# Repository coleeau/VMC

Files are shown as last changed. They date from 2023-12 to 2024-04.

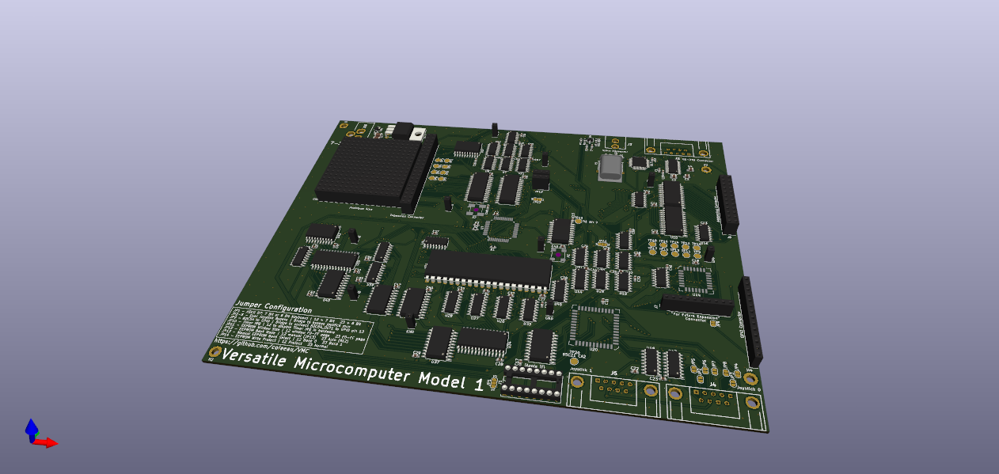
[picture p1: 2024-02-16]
Hardware/Micro/Micro.png

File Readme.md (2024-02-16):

# Versatile Micro Computer

The Versatile Micro Computer (VMC for short) is a 6502 platform designed to be Powerful, expandable, and versatile

The VMC was designed as a project to express everything I have leared in electrical engineering,
and as a way to learn more concepts in electrical engineering, computer engineering and computer science

## Repository layout

- Hardware: KiCad files for the Hardware side of the VMC
- Reference: Reference documents
- Software: all sorts of programs
- Tools: Tools for testing

## Licensing

- Hardware: Global License applies to all files
- Reference: License depends on file. Global license likely applies to any non datasheet files.
- Software: Global License applies to all files outside of /3rd Party Software/ folder
- Tools: Global License does not apply to any file.

## Roadmap

### Complete

- Design of Revision 1 Arcitecture
- Revision 1 PCB Layout
- Bootstrap Program "Rudimentery"
- Assemble and
### In Progress

- Test Revision 1 Hardware
- Write Bios

### Planned

- Port Basic
- Replace glue logic with PLD for better speed and cost efficiancy

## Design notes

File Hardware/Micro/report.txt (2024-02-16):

Info: Processing symbol 'C1:Capacitor_SMD:C_0603_1608Metric_Pad1.08x0.95mm_HandSolder'.
Info: Processing symbol 'C2:Capacitor_SMD:C_0805_2012Metric_Pad1.18x1.45mm_HandSolder'.
Info: Processing symbol 'JP8:Jumper:SolderJumper-2_P1.3mm_Open_RoundedPad1.0x1.5mm'.
Info: Processing symbol 'C3:Capacitor_SMD:C_0805_2012Metric_Pad1.18x1.45mm_HandSolder'.
Info: Processing symbol 'JP9:Jumper:SolderJumper-2_P1.3mm_Open_RoundedPad1.0x1.5mm'.
Info: Processing symbol 'C4:Capacitor_SMD:C_0805_2012Metric_Pad1.18x1.45mm_HandSolder'.
Info: Processing symbol 'JP10:Jumper:SolderJumper-3_P1.3mm_Open_RoundedPad1.0x1.5mm_NumberLabels'.
Info: Processing symbol 'C5:Capacitor_SMD:C_0603_1608Metric_Pad1.08x0.95mm_HandSolder'.
Info: Processing symbol 'C6:Capacitor_SMD:C_0603_1608Metric_Pad1.08x0.95mm_HandSolder'.
Info: Processing symbol 'C7:Capacitor_SMD:C_0603_1608Metric_Pad1.08x0.95mm_HandSolder'.
Info: Processing symbol 'C8:Capacitor_SMD:C_0603_1608Metric_Pad1.08x0.95mm_HandSolder'.
Info: Processing symbol 'U19:Package_SO:SOIC-14_3.9x8.7mm_P1.27mm'.
Info: Processing symbol 'C9:Capacitor_SMD:C_0603_1608Metric_Pad1.08x0.95mm_HandSolder'.
Info: Processing symbol 'JP11:Jumper:SolderJumper-3_P1.3mm_Bridged12_RoundedPad1.0x1.5mm_NumberLabels'.
Info: Processing symbol 'C10:Capacitor_SMD:C_0603_1608Metric_Pad1.08x0.95mm_HandSolder'.
Info: Processing symbol 'U9:Package_SO:SOIC-14_3.9x8.7mm_P1.27mm'.
Info: Processing symbol 'C11:Capacitor_SMD:C_0603_1608Metric_Pad1.08x0.95mm_HandSolder'.
Info: Processing symbol 'JP12:Jumper:SolderJumper-3_P1.3mm_Bridged12_RoundedPad1.0x1.5mm_NumberLabels'.
Info: Processing symbol 'C12:Capacitor_SMD:C_0603_1608Metric_Pad1.08x0.95mm_HandSolder'.
Info: Processing symbol 'U23:Package_SO:SOIC-20W_7.5x12.8mm_P1.27mm'.
Info: Processing symbol 'C13:Capacitor_SMD:C_0603_1608Metric_Pad1.08x0.95mm_HandSolder'.
Info: Processing symbol 'JP13:Connector_PinSocket_2.54mm:PinSocket_1x03_P2.54mm_Vertical'.
Info: Processing symbol 'C14:Capacitor_SMD:C_0603_1608Metric_Pad1.08x0.95mm_HandSolder'.
Info: Processing symbol 'U10:Package_SO:SOIC-24W_7.5x15.4mm_P1.27mm'.
Info: Processing symbol 'C15:Capacitor_SMD:C_0603_1608Metric_Pad1.08x0.95mm_HandSolder'.
Info: Processing symbol 'Q4:Package_TO_SOT_SMD:SOT-23_Handsoldering'.
Info: Processing symbol 'C16:Capacitor_SMD:C_0603_1608Metric_Pad1.08x0.95mm_HandSolder'.
Info: Processing symbol 'R1:Resistor_SMD:R_0603_1608Metric_Pad0.98x0.95mm_HandSolder'.
Info: Processing symbol 'C17:Capacitor_SMD:C_0603_1608Metric_Pad1.08x0.95mm_HandSolder'.
Info: Processing symbol 'R2:Resistor_SMD:R_0603_1608Metric_Pad0.98x0.95mm_HandSolder'.
Info: Processing symbol 'C18:Capacitor_SMD:C_0603_1608Metric_Pad1.08x0.95mm_HandSolder'.
Info: Processing symbol 'R3:Resistor_SMD:R_0603_1608Metric_Pad0.98x0.95mm_HandSolder'.
Info: Processing symbol 'C19:Capacitor_SMD:C_0603_1608Metric_Pad1.08x0.95mm_HandSolder'.
Info: Processing symbol 'R4:Resistor_SMD:R_0603_1608Metric_Pad0.98x0.95mm_HandSolder'.
Info: Processing symbol 'C20:Capacitor_SMD:C_0603_1608Metric_Pad1.08x0.95mm_HandSolder'.
Info: Processing symbol 'R5:Resistor_SMD:R_0603_1608Metric_Pad0.98x0.95mm_HandSolder'.
Info: Processing symbol 'C21:Capacitor_SMD:C_0603_1608Metric_Pad1.08x0.95mm_HandSolder'.
Info: Processing symbol 'R6:Resistor_SMD:R_0603_1608Metric_Pad0.98x0.95mm_HandSolder'.
Info: Processing symbol 'C22:Capacitor_SMD:C_0603_1608Metric_Pad1.08x0.95mm_HandSolder'.
Info: Processing symbol 'R7:Resistor_SMD:R_0603_1608Metric_Pad0.98x0.95mm_HandSolder'.
Info: Processing symbol 'C23:Capacitor_SMD:C_0603_1608Metric_Pad1.08x0.95mm_HandSolder'.
Info: Processing symbol 'U24:Package_DIP:DIP-40_W15.24mm'.
Info: Processing symbol 'C24:Capacitor_SMD:C_0603_1608Metric_Pad1.08x0.95mm_HandSolder'.
Info: Processing symbol 'U20:Package_LCC:PLCC-44'.
Info: Processing symbol 'C25:Capacitor_SMD:C_0603_1608Metric_Pad1.08x0.95mm_HandSolder'.
Info: Processing symbol 'R8:Resistor_SMD:R_0603_1608Metric_Pad0.98x0.95mm_HandSolder'.
Info: Processing symbol 'C26:Capacitor_SMD:C_0603_1608Metric_Pad1.08x0.95mm_HandSolder'.
Info: Processing symbol 'U21:Package_SO:SOIC-14_3.9x8.7mm_P1.27mm'.
Info: Processing symbol 'C27:Capacitor_SMD:C_0603_1608Metric_Pad1.08x0.95mm_HandSolder'.
Info: Processing symbol 'U12:Package_SO:SOIC-20W_7.5x12.8mm_P1.27mm'.
Info: Processing symbol 'C28:Capacitor_SMD:C_0603_1608Metric_Pad1.08x0.95mm_HandSolder'.
Info: Processing symbol 'R9:Resistor_SMD:R_0603_1608Metric_Pad0.98x0.95mm_HandSolder'.
Info: Processing symbol 'C29:Capacitor_SMD:C_0603_1608Metric_Pad1.08x0.95mm_HandSolder'.
Info: Processing symbol 'R10:Resistor_SMD:R_0603_1608Metric_Pad0.98x0.95mm_HandSolder'.
Info: Processing symbol 'C30:Capacitor_SMD:C_0603_1608Metric_Pad1.08x0.95mm_HandSolder'.
Info: Processing symbol 'R11:Resistor_SMD:R_0603_1608Metric_Pad0.98x0.95mm_HandSolder'.
Info: Processing symbol 'C31:Capacitor_SMD:C_0603_1608Metric_Pad1.08x0.95mm_HandSolder'.
Info: Processing symbol 'TP1:TestPoint:TestPoint_Pad_D2.5mm'.
Info: Processing symbol 'C32:Capacitor_SMD:C_0603_1608Metric_Pad1.08x0.95mm_HandSolder'.
Info: Processing symbol 'U13:Package_TO_SOT_THT:TO-220-3_Horizontal_TabDown'.
Info: Processing symbol 'C33:Capacitor_SMD:C_0603_1608Metric_Pad1.08x0.95mm_HandSolder'.
Info: Processing symbol 'TP2:TestPoint:TestPoint_Pad_D2.5mm'.
Info: Processing symbol 'C34:Capacitor_SMD:C_0603_1608Metric_Pad1.08x0.95mm_HandSolder'.
Info: Processing symbol 'U22:Package_SO:SOIC-14_3.9x8.7mm_P1.27mm'.
Info: Processing symbol 'C35:Capacitor_SMD:C_0603_1608Metric_Pad1.08x0.95mm_HandSolder'.
Info: Processing symbol 'TP3:TestPoint:TestPoint_Pad_D2.5mm'.
Info: Processing symbol 'C36:Capacitor_SMD:C_0603_1608Metric_Pad1.08x0.95mm_HandSolder'.
Info: Processing symbol 'U14:Package_LCC:PLCC-28'.
Info: Processing symbol 'C37:Capacitor_SMD:C_0603_1608Metric_Pad1.08x0.95mm_HandSolder'.
Info: Processing symbol 'TP4:TestPoint:TestPoint_Pad_D2.5mm'.
Info: Processing symbol 'C38:Capacitor_SMD:C_0603_1608Metric_Pad1.08x0.95mm_HandSolder'.
Info: Processing symbol 'U15:Package_SO:SOIC-20W_7.5x12.8mm_P1.27mm'.
Info: Processing symbol 'C39:Capacitor_SMD:C_0603_1608Metric_Pad1.08x0.95mm_HandSolder'.
Info: Processing symbol 'TP5:TestPoint:TestPoint_Pad_D2.5mm'.
Info: Processing symbol 'C40:Capacitor_SMD:C_0603_1608Metric_Pad1.08x0.95mm_HandSolder'.
Info: Processing symbol 'U16:Package_SO:SOIC-14_3.9x8.7mm_P1.27mm'.
Info: Processing symbol 'C41:Capacitor_SMD:C_0603_1608Metric_Pad1.08x0.95mm_HandSolder'.
Info: Processing symbol 'TP6:TestPoint:TestPoint_Pad_D2.5mm'.
Info: Processing symbol 'C42:Capacitor_SMD:C_0603_1608Metric_Pad1.08x0.95mm_HandSolder'.
Info: Processing symbol 'U17:Package_QFP:TQFP-48_7x7mm_P0.5mm'.
Info: Processing symbol 'C43:Capacitor_SMD:C_0603_1608Metric_Pad1.08x0.95mm_HandSolder'.
Info: Processing symbol 'TP7:TestPoint:TestPoint_Pad_D2.5mm'.
Info: Processing symbol 'C44:Capacitor_SMD:C_0603_1608Metric_Pad1.08x0.95mm_HandSolder'.
Info: Processing symbol 'U11:Package_SO:SOIC-24W_7.5x15.4mm_P1.27mm'.
Info: Processing symbol 'C45:Capacitor_SMD:C_0603_1608Metric_Pad1.08x0.95mm_HandSolder'.
Info: Processing symbol 'TP8:TestPoint:TestPoint_Pad_D2.5mm'.
Info: Processing symbol 'C46:Capacitor_SMD:C_0603_1608Metric_Pad1.08x0.95mm_HandSolder'.
Info: Processing symbol 'U32:Package_SO:SOIC-14_3.9x8.7mm_P1.27mm'.
Info: Processing symbol 'C47:Capacitor_SMD:C_0603_1608Metric_Pad1.08x0.95mm_HandSolder'.
Info: Processing symbol 'U1:Package_QFP:MQFP-44_10x10mm_P0.8mm'.
Info: Processing symbol 'C48:Capacitor_SMD:C_0603_1608Metric_Pad1.08x0.95mm_HandSolder'.
Info: Processing symbol 'U2:Package_SO:SOIC-28W_7.5x17.9mm_P1.27mm'.
Info: Processing symbol 'C49:'.
Info: Processing symbol 'U40:Package_SO:SOIC-16_3.9x9.9mm_P1.27mm'.
Info: Processing symbol 'C50:'.
Info: Processing symbol 'U39:Package_SO:SOIC-16_3.9x9.9mm_P1.27mm'.
Info: Processing symbol 'C51:Capacitor_SMD:C_0603_1608Metric_Pad1.08x0.95mm_HandSolder'.
Info: Processing symbol 'U3:Package_SO:SOIC-28W_7.5x17.9mm_P1.27mm'.
Info: Processing symbol 'C52:Capacitor_SMD:C_0603_1608Metric_Pad1.08x0.95mm_HandSolder'.
Info: Processing symbol 'U4:Package_SO:SOIC-14_3.9x8.7mm_P1.27mm'.
Info: Processing symbol 'C53:Capacitor_SMD:C_0603_1608Metric_Pad1.08x0.95mm_HandSolder'.
Info: Processing symbol 'U31:Package_SO:SOIC-14_3.9x8.7mm_P1.27mm'.
Info: Processing symbol 'C54:Capacitor_SMD:C_0603_1608Metric_Pad1.08x0.95mm_HandSolder'.
Info: Processing symbol 'U5:Package_SO:SOIC-14_3.9x8.7mm_P1.27mm'.
Info: Processing symbol 'C55:Capacitor_SMD:C_0603_1608Metric_Pad1.08x0.95mm_HandSolder'.
Info: Processing symbol 'U30:Package_SO:SOIC-14_3.9x8.7mm_P1.27mm'.
Info: Processing symbol 'C56:Capacitor_SMD:C_0603_1608Metric_Pad1.08x0.95mm_HandSolder'.
Info: Processing symbol 'U29:Package_SO:SOIC-14_3.9x8.7mm_P1.27mm'.
Info: Processing symbol 'C57:Capacitor_SMD:C_0603_1608Metric_Pad1.08x0.95mm_HandSolder'.
Info: Processing symbol 'U28:Package_SO:SOIC-16_3.9x9.9mm_P1.27mm'.
Info: Processing symbol 'D1:Diode_SMD:D_SOD-123'.
Info: Processing symbol 'D2:Diode_SMD:D_SOD-123'.
Info: Processing symbol 'D3:Diode_SMD:D_SOD-123'.
Info: Processing symbol 'D4:Diode_SMD:D_PowerDI-123'.
Info: Processing symbol 'U27:Package_SO:SOIC-16_3.9x9.9mm_P1.27mm'.
Info: Processing symbol 'F1:Fuse:Fuse_0603_1608Metric_Pad1.05x0.95mm_HandSolder'.
Info: Processing symbol 'U6:Package_SO:SOIC-14_3.9x8.7mm_P1.27mm'.
Info: Processing symbol 'J1:Package_DIP:DIP-16_W7.62mm_Socket'.
Info: Processing symbol 'J2:SamacSys_Parts:L717SDE09PA4CH3F'.
Info: Processing symbol 'U38:Package_SO:SOIC-16_3.9x9.9mm_P1.27mm'.
Info: Processing symbol 'U37:Package_SO:SOIC-20W_7.5x12.8mm_P1.27mm'.
Info: Processing symbol 'J3:1560099E'.
Info: Processing symbol 'U26:Package_SO:SOIC-16_3.9x9.9mm_P1.27mm'.
Info: Processing symbol 'J4:SamacSys_Parts:L717SDE09PA4CH3F'.
Info: Processing symbol 'U36:Package_SO:SOIC-20W_7.5x12.8mm_P1.27mm'.
Info: Processing symbol 'U35:Package_SO:SOIC-20W_7.5x12.8mm_P1.27mm'.
Info: Processing symbol 'J5:SamacSys_Parts:L717SDE09PA4CH3F'.
Info: Processing symbol 'U34:Package_SO:SOIC-28W_7.5x17.9mm_P1.27mm'.
Info: Processing symbol 'U33:Package_SO:SOIC-16_3.9x9.9mm_P1.27mm'.
Info: Processing symbol 'J6:Connector_PinSocket_2.54mm:PinSocket_1x14_P2.54mm_Vertical'.
Info: Processing symbol 'J7:Connector_PinSocket_2.54mm:PinSocket_1x10_P2.54mm_Vertical'.
Info: Processing symbol 'J8:Connector_PinSocket_2.54mm:PinSocket_2x11_P2.54mm_Vertical'.
Info: Processing symbol 'U7:Package_SO:SOIC-14_3.9x8.7mm_P1.27mm'.
Info: Processing symbol 'J9:Connector_PinSocket_2.54mm:PinSocket_2x20_P2.54mm_Vertical'.
Info: Processing symbol 'U25:Package_SO:SOIC-28W_7.5x18.7mm_P1.27mm'.
Info: Processing symbol 'J10:694106301002_1'.
Info: Processing symbol 'U8:Package_SO:SOIC-14_3.9x8.7mm_P1.27mm'.
Info: Processing symbol 'JP1:Jumper:SolderJumper-3_P1.3mm_Open_RoundedPad1.0x1.5mm_NumberLabels'.
Info: Processing symbol 'U18:Package_SO:TSSOP-28_4.4x9.7mm_P0.65mm'.
Info: Processing symbol 'JP2:Jumper:SolderJumper-2_P1.3mm_Open_RoundedPad1.0x1.5mm'.
Info: Processing symbol 'JP3:Jumper:SolderJumper-2_P1.3mm_Open_RoundedPad1.0x1.5mm'.
Info: Processing symbol 'JP4:Jumper:SolderJumper-2_P1.3mm_Open_RoundedPad1.0x1.5mm'.
Info: Processing symbol 'JP5:Jumper:SolderJumper-2_P1.3mm_Open_RoundedPad1.0x1.5mm'.
Info: Processing symbol 'JP6:Jumper:SolderJumper-2_P1.3mm_Open_RoundedPad1.0x1.5mm'.
Info: Processing symbol 'JP7:Jumper:SolderJumper-2_P1.3mm_Open_RoundedPad1.0x1.5mm'.
Info: Processing symbol 'U41:Package_SO:SOIC-16_3.9x9.9mm_P1.27mm'.
Info: Processing symbol 'U42:Package_SO:SOIC-20W_7.5x12.8mm_P1.27mm'.
Info: Processing symbol 'U43:Package_SO:SOIC-20W_7.5x12.8mm_P1.27mm'.
Info: Processing symbol 'U44:Package_SO:SOIC-16_3.9x9.9mm_P1.27mm'.
Info: Processing symbol 'U45:Package_SO:SOIC-16_3.9x9.9mm_P1.27mm'.
Info: Processing symbol 'U46:Package_SO:SOIC-14_3.9x8.7mm_P1.27mm'.
Info: Processing symbol 'U47:Package_SO:SOIC-16_3.9x9.9mm_P1.27mm'.
Info: Processing symbol 'U48:Package_SO:SOIC-16_3.9x9.9mm_P1.27mm'.
Info: Processing symbol 'U49:Package_SO:SOIC-14_3.9x8.7mm_P1.27mm'.
Info: Processing symbol 'X1:Oscillator:Oscillator_SMD_Fordahl_DFAS11-4Pin_7.0x5.0mm'.
Info: Processing symbol 'X2:Oscillator:Oscillator_SMD_Abracon_ASV-4Pin_7.0x5.1mm_HandSoldering'.
Info: Processing symbol 'Y1:Crystal:Crystal_HC49-U_Horizontal_1EP_style2'.
Add C17 (footprint 'Capacitor_SMD:C_0603_1608Metric_Pad1.08x0.95mm_HandSolder').
Add C18 (footprint 'Capacitor_SMD:C_0603_1608Metric_Pad1.08x0.95mm_HandSolder').
Add C19 (footprint 'Capacitor_SMD:C_0603_1608Metric_Pad1.08x0.95mm_HandSolder').
Add C20 (footprint 'Capacitor_SMD:C_0603_1608Metric_Pad1.08x0.95mm_HandSolder').
Add C21 (footprint 'Capacitor_SMD:C_0603_1608Metric_Pad1.08x0.95mm_HandSolder').
Add C22 (footprint 'Capacitor_SMD:C_0603_1608Metric_Pad1.08x0.95mm_HandSolder').
Add C23 (footprint 'Capacitor_SMD:C_0603_1608Metric_Pad1.08x0.95mm_HandSolder').
Add C24 (footprint 'Capacitor_SMD:C_0603_1608Metric_Pad1.08x0.95mm_HandSolder').
Add C25 (footprint 'Capacitor_SMD:C_0603_1608Metric_Pad1.08x0.95mm_HandSolder').
Add C26 (footprint 'Capacitor_SMD:C_0603_1608Metric_Pad1.08x0.95mm_HandSolder').
Add C27 (footprint 'Capacitor_SMD:C_0603_1608Metric_Pad1.08x0.95mm_HandSolder').
Add C28 (footprint 'Capacitor_SMD:C_0603_1608Metric_Pad1.08x0.95mm_HandSolder').
Add C29 (footprint 'Capacitor_SMD:C_0603_1608Metric_Pad1.08x0.95mm_HandSolder').
Add C30 (footprint 'Capacitor_SMD:C_0603_1608Metric_Pad1.08x0.95mm_HandSolder').
Add C31 (footprint 'Capacitor_SMD:C_0603_1608Metric_Pad1.08x0.95mm_HandSolder').
Add C32 (footprint 'Capacitor_SMD:C_0603_1608Metric_Pad1.08x0.95mm_HandSolder').
Add C33 (footprint 'Capacitor_SMD:C_0603_1608Metric_Pad1.08x0.95mm_HandSolder').
Add C34 (footprint 'Capacitor_SMD:C_0603_1608Metric_Pad1.08x0.95mm_HandSolder').
Add C35 (footprint 'Capacitor_SMD:C_0603_1608Metric_Pad1.08x0.95mm_HandSolder').
Add C36 (footprint 'Capacitor_SMD:C_0603_1608Metric_Pad1.08x0.95mm_HandSolder').
Add C37 (footprint 'Capacitor_SMD:C_0603_1608Metric_Pad1.08x0.95mm_HandSolder').
Add C38 (footprint 'Capacitor_SMD:C_0603_1608Metric_Pad1.08x0.95mm_HandSolder').
Add C39 (footprint 'Capacitor_SMD:C_0603_1608Metric_Pad1.08x0.95mm_HandSolder').
Add C40 (footprint 'Capacitor_SMD:C_0603_1608Metric_Pad1.08x0.95mm_HandSolder').
Add C41 (footprint 'Capacitor_SMD:C_0603_1608Metric_Pad1.08x0.95mm_HandSolder').
Add C42 (footprint 'Capacitor_SMD:C_0603_1608Metric_Pad1.08x0.95mm_HandSolder').
Add C43 (footprint 'Capacitor_SMD:C_0603_1608Metric_Pad1.08x0.95mm_HandSolder').
Add C44 (footprint 'Capacitor_SMD:C_0603_1608Metric_Pad1.08x0.95mm_HandSolder').
Add C45 (footprint 'Capacitor_SMD:C_0603_1608Metric_Pad1.08x0.95mm_HandSolder').
Add C46 (footprint 'Capacitor_SMD:C_0603_1608Metric_Pad1.08x0.95mm_HandSolder').
Add C47 (footprint 'Capacitor_SMD:C_0603_1608Metric_Pad1.08x0.95mm_HandSolder').
Add C48 (footprint 'Capacitor_SMD:C_0603_1608Metric_Pad1.08x0.95mm_HandSolder').
Add C51 (footprint 'Capacitor_SMD:C_0603_1608Metric_Pad1.08x0.95mm_HandSolder').
Add C52 (footprint 'Capacitor_SMD:C_0603_1608Metric_Pad1.08x0.95mm_HandSolder').
Add C53 (footprint 'Capacitor_SMD:C_0603_1608Metric_Pad1.08x0.95mm_HandSolder').
Add C54 (footprint 'Capacitor_SMD:C_0603_1608Metric_Pad1.08x0.95mm_HandSolder').
Add C55 (footprint 'Capacitor_SMD:C_0603_1608Metric_Pad1.08x0.95mm_HandSolder').
Add C56 (footprint 'Capacitor_SMD:C_0603_1608Metric_Pad1.08x0.95mm_HandSolder').
Add C57 (footprint 'Capacitor_SMD:C_0603_1608Metric_Pad1.08x0.95mm_HandSolder').
Add D4 (footprint 'Diode_SMD:D_PowerDI-123').
Add F1 (footprint 'Fuse:Fuse_0603_1608Metric_Pad1.05x0.95mm_HandSolder').
Change J3 footprint from 'SamacSys_Parts:1560099E' to '1560099E'.
Add J8 (footprint 'Connector_PinSocket_2.54mm:PinSocket_2x11_P2.54mm_Vertical').
Add J9 (footprint 'Connector_PinSocket_2.54mm:PinSocket_2x20_P2.54mm_Vertical').
Add J10 (footprint '694106301002_1').
Add JP1 (footprint 'Jumper:SolderJumper-3_P1.3mm_Open_RoundedPad1.0x1.5mm_NumberLabels').
Change JP10 footprint from 'Jumper:SolderJumper-3_P1.3mm_Open_Pad1.0x1.5mm_NumberLabels' to 'Jumper:SolderJumper-3_P1.3mm_Open_RoundedPad1.0x1.5mm_NumberLabels'.
Add JP11 (footprint 'Jumper:SolderJumper-3_P1.3mm_Bridged12_RoundedPad1.0x1.5mm_NumberLabels').
Add JP12 (footprint 'Jumper:SolderJumper-3_P1.3mm_Bridged12_RoundedPad1.0x1.5mm_NumberLabels').
Add JP13 (footprint 'Connector_PinSocket_2.54mm:PinSocket_1x03_P2.54mm_Vertical').
Add net /Video/Video Combination Logic/Composite vid/Y.
Reconnect R7 pin 2 from /VIdeo/Video Combination Logic/Composite vid/Y to /Video/Video Combination Logic/Composite vid/Y.
Add net /Video/Video Combination Logic/Composite vid/CSYNC.
Reconnect R8 pin 1 from /VIdeo/Video Combination Logic/Composite vid/CSYNC to /Video/Video Combination Logic/Composite vid/CSYNC.
Add TP1 (footprint 'TestPoint:TestPoint_Pad_D2.5mm').
Add TP2 (footprint 'TestPoint:TestPoint_Pad_D2.5mm').
Add TP3 (footprint 'TestPoint:TestPoint_Pad_D2.5mm').
Add TP4 (footprint 'TestPoint:TestPoint_Pad_D2.5mm').
Add TP5 (footprint 'TestPoint:TestPoint_Pad_D2.5mm').
Add TP6 (footprint 'TestPoint:TestPoint_Pad_D2.5mm').
Add TP7 (footprint 'TestPoint:TestPoint_Pad_D2.5mm').
Add TP8 (footprint 'TestPoint:TestPoint_Pad_D2.5mm').
Update U4 symbol association from /7bcaf41d-6d3d-4f33-82ee-7daa1c8431e0/5354c1c1-bc4f-4336-8cec-d4451e44db87 to /7bcaf41d-6d3d-4f33-82ee-7daa1c8431e0/391ce00c-f2b4-4eee-bc8b-14090f666e66.
Add net Net-(U30-Pad8).
Reconnect U5 pin 5 from Net-(U5-Pad1) to Net-(U30-Pad8).
Add net Net-(U30-Pad10).
Reconnect U5 pin 1 from Net-(U5-Pad1) to Net-(U30-Pad10).
Update U6 symbol association from /7bcaf41d-6d3d-4f33-82ee-7daa1c8431e0/6c6bb8ff-625e-40b3-9856-8a58038bb5e4 to /7bcaf41d-6d3d-4f33-82ee-7daa1c8431e0/4c8455cb-f38c-4708-88b6-d5893fa9d499.
Update U7 symbol association from /7bcaf41d-6d3d-4f33-82ee-7daa1c8431e0/332360da-0865-4aff-a77d-b443ebf3b65f to /7bcaf41d-6d3d-4f33-82ee-7daa1c8431e0/6dddda0c-0e40-49b6-8176-9f8dc502a90e.
Update U8 symbol association from /7bcaf41d-6d3d-4f33-82ee-7daa1c8431e0/c1ef6448-b6f6-4eba-99e9-491106cb0455 to /7bcaf41d-6d3d-4f33-82ee-7daa1c8431e0/e763f917-e82a-4c54-9560-08f6f9770648.
Reconnect U8 pin 8 from Net-(U5-Pad1) to Net-(U30-Pad10).
Update U9 symbol association from /7bcaf41d-6d3d-4f33-82ee-7daa1c8431e0/9c1bae30-8146-4c0e-84f0-774d193a82bb to /7bcaf41d-6d3d-4f33-82ee-7daa1c8431e0/e4b5f2e2-700d-4896-b4c6-00f3e92178fd.
Add net Net-(J8-Pin_20).
Reconnect U10 pin 6 from unconnected-(U10-S5-Pad6) to Net-(J8-Pin_20).
Add net Net-(J8-Pin_19).
Reconnect U10 pin 5 from unconnected-(U10-S4-Pad5) to Net-(J8-Pin_19).
Add net Net-(J8-Pin_18).
Reconnect U10 pin 4 from unconnected-(U10-S3-Pad4) to Net-(J8-Pin_18).
Add net Net-(J8-Pin_17).
Reconnect U10 pin 3 from Net-(J8-Pin_10) to Net-(J8-Pin_17).
Add net unconnected-(U10-S1-Pad2).
Reconnect U10 pin 2 from Net-(J8-Pin_9) to unconnected-(U10-S1-Pad2).
Add net Net-(J8-Pin_16).
Reconnect U11 pin 17 from Net-(U11-S15) to Net-(J8-Pin_16).
Add net Net-(J8-Pin_15).
Reconnect U11 pin 16 from unconnected-(U11-S14-Pad16) to Net-(J8-Pin_15).
Add net Net-(J8-Pin_14).
Reconnect U11 pin 15 from unconnected-(U11-S13-Pad15) to Net-(J8-Pin_14).
Add net Net-(J8-Pin_13).
Reconnect U11 pin 14 from unconnected-(U11-S12-Pad14) to Net-(J8-Pin_13).
Add net Net-(J8-Pin_12).
Reconnect U11 pin 13 from unconnected-(U11-S11-Pad13) to Net-(J8-Pin_12).
Add net Net-(J8-Pin_11).
Reconnect U11 pin 11 from unconnected-(U11-S10-Pad11) to Net-(J8-Pin_11).
Reconnect U11 pin 10 from unconnected-(U11-S9-Pad10) to Net-(J8-Pin_10).
Reconnect U11 pin 9 from unconnected-(U11-S8-Pad9) to Net-(J8-Pin_9).
Add U13 (footprint 'Package_TO_SOT_THT:TO-220-3_Horizontal_TabDown').
Update U19 symbol association from /60bf3c7c-7133-4ca1-aa44-3c0fc6d461d6/3cba59ac-4426-4a73-b4f4-1560fd894bbd/b821332d-7200-400b-bb4b-fe5db0de1882 to /60bf3c7c-7133-4ca1-aa44-3c0fc6d461d6/3cba59ac-4426-4a73-b4f4-1560fd894bbd/c3ecb09d-51e2-4e99-a5f0-d144f7a4d6c6.
Add net /Video/Video Combination Logic/VSYNC.
Reconnect U19 pin 5 from /VIdeo/Video Combination Logic/VSYNC to /Video/Video Combination Logic/VSYNC.
Add net /Video/Video Combination Logic/HSYNC.
Reconnect U19 pin 4 from /VIdeo/Video Combination Logic/HSYNC to /Video/Video Combination Logic/HSYNC.
Add net /Video/Video Combination Logic/DOT_OUT.
Reconnect U19 pin 2 from /VIdeo/Video Combination Logic/DOT_OUT to /Video/Video Combination Logic/DOT_OUT.
Update U21 symbol association from /7bcaf41d-6d3d-4f33-82ee-7daa1c8431e0/e98823ee-305d-44fd-81ae-f2e59adfc01e to /7bcaf41d-6d3d-4f33-82ee-7daa1c8431e0/8e518423-3594-4b1e-a90a-5ccb484f70fb.
Reconnect U21 pin 14 from unconnected-(U21E-VCC-Pad14) to +5V.
Reconnect U21 pin 7 from unconnected-(U21E-GND-Pad7) to GND.
Update U22 symbol association from /df04dcad-608f-4a5f-9459-edcdeb427672/7047d1ab-0072-46ed-9065-c20aee2d31ad to /df04dcad-608f-4a5f-9459-edcdeb427672/e3c288b7-e6fb-4a5a-a702-b2b577d59b8c.
Reconnect U22 pin 5 from Net-(U11-S15) to Net-(J8-Pin_16).
Update U24 properties.
Reconnect U24 pin 40 from /VIdeo/Video Combination Logic/VSYNC to /Video/Video Combination Logic/VSYNC.
Reconnect U24 pin 39 from /VIdeo/Video Combination Logic/HSYNC to /Video/Video Combination Logic/HSYNC.
Add net /Video/CHRAM_Adress_Mux/RS0.
Reconnect U24 pin 38 from /VIdeo/CHRAM_Adress_Mux/RS0 to /Video/CHRAM_Adress_Mux/RS0.
Add net /Video/CHRAM_Adress_Mux/RS1.
Reconnect U24 pin 37 from /VIdeo/CHRAM_Adress_Mux/RS1 to /Video/CHRAM_Adress_Mux/RS1.
Add net /Video/CHRAM_Adress_Mux/RS2.
Reconnect U24 pin 36 from /VIdeo/CHRAM_Adress_Mux/RS2 to /Video/CHRAM_Adress_Mux/RS2.
Add net /Video/CHRAM_Adress_Mux/RS3.
Reconnect U24 pin 35 from /VIdeo/CHRAM_Adress_Mux/RS3 to /Video/CHRAM_Adress_Mux/RS3.
Add net /Video/VID_CLK_GEN/CHR_CLK.
Reconnect U24 pin 21 from /VIdeo/VID_CLK_GEN/CHR_CLK to /Video/VID_CLK_GEN/CHR_CLK.
Add net /Video/Video Combination Logic/CURSOR.
Reconnect U24 pin 19 from /VIdeo/Video Combination Logic/CURSOR to /Video/Video Combination Logic/CURSOR.
Add net /Video/Video Combination Logic/DISP_EN.
Reconnect U24 pin 18 from /VIdeo/Video Combination Logic/DISP_EN to /Video/Video Combination Logic/DISP_EN.
Add net /Video/VRAM_Adress_Mux/MA13.
Reconnect U24 pin 17 from /VIdeo/MA13 to /Video/VRAM_Adress_Mux/MA13.
Add net /Video/VRAM_Adress_Mux/MA12.
Reconnect U24 pin 16 from /VIdeo/MA12 to /Video/VRAM_Adress_Mux/MA12.
Add net /Video/MA11.
Reconnect U24 pin 15 from /VIdeo/MA11 to /Video/MA11.
Add net /Video/VRAM_Adress_Mux/MA10.
Reconnect U24 pin 14 from /VIdeo/MA10 to /Video/VRAM_Adress_Mux/MA10.
Add net /Video/VRAM_Adress_Mux/MA9.
Reconnect U24 pin 13 from /VIdeo/MA9 to /Video/VRAM_Adress_Mux/MA9.
Add net /Video/VRAM_Adress_Mux/MA8.
Reconnect U24 pin 12 from /VIdeo/MA8 to /Video/VRAM_Adress_Mux/MA8.
Add net /Video/VRAM_Adress_Mux/MA7.
Reconnect U24 pin 11 from /VIdeo/MA7 to /Video/VRAM_Adress_Mux/MA7.
Add net /Video/VRAM_Adress_Mux/MA6.
Reconnect U24 pin 10 from /VIdeo/MA6 to /Video/VRAM_Adress_Mux/MA6.
Add net /Video/VRAM_Adress_Mux/MA5.
Reconnect U24 pin 9 from /VIdeo/MA5 to /Video/VRAM_Adress_Mux/MA5.
Add net /Video/VRAM_Adress_Mux/MA4.
Reconnect U24 pin 8 from /VIdeo/MA4 to /Video/VRAM_Adress_Mux/MA4.
Add net /Video/VRAM_Adress_Mux/MA3.
Reconnect U24 pin 7 from /VIdeo/MA3 to /Video/VRAM_Adress_Mux/MA3.
Add net /Video/VRAM_Adress_Mux/MA2.
Reconnect U24 pin 6 from /VIdeo/VRAM_Adress_Mux/MA2 to /Video/VRAM_Adress_Mux/MA2.
Add net /Video/VRAM_Adress_Mux/MA1.
Reconnect U24 pin 5 from /VIdeo/MA1 to /Video/VRAM_Adress_Mux/MA1.
Add net /Video/VRAM_Adress_Mux/MA0.
Reconnect U24 pin 4 from /VIdeo/MA0 to /Video/VRAM_Adress_Mux/MA0.
Update U25 properties.
Add net /Video/CHRAM_Adress_Mux/CHRAMA8.
Reconnect U25 pin 25 from /VIdeo/CHRAM_Adress_Mux/CHRAMA8 to /Video/CHRAM_Adress_Mux/CHRAMA8.
Add net /Video/CHRAM_Adress_Mux/CHRAMA9.
Reconnect U25 pin 24 from /VIdeo/CHRAM_Adress_Mux/CHRAMA9 to /Video/CHRAM_Adress_Mux/CHRAMA9.
Add net /Video/CHRAM_Adress_Mux/CHRAMA11.
Reconnect U25 pin 23 from /VIdeo/CHRAM_Adress_Mux/CHRAMA11 to /Video/CHRAM_Adress_Mux/CHRAMA11.
Add net /Video/CHRAM_Adress_Mux/CHRAMA10.
Reconnect U25 pin 21 from /VIdeo/CHRAM_Adress_Mux/CHRAMA10 to /Video/CHRAM_Adress_Mux/CHRAMA10.
Add net /Video/CHRAM data buffer/CHRAM_D7.
Reconnect U25 pin 19 from /VIdeo/CHRAM data buffer/CHRAM_D7 to /Video/CHRAM data buffer/CHRAM_D7.
Add net /Video/CHRAM data buffer/CHRAM_D6.
Reconnect U25 pin 18 from /VIdeo/CHRAM data buffer/CHRAM_D6 to /Video/CHRAM data buffer/CHRAM_D6.
Add net /Video/CHRAM data buffer/CHRAM_D5.
Reconnect U25 pin 17 from /VIdeo/CHRAM data buffer/CHRAM_D5 to /Video/CHRAM data buffer/CHRAM_D5.
Add net /Video/CHRAM data buffer/CHRAM_D4.
Reconnect U25 pin 16 from /VIdeo/CHRAM data buffer/CHRAM_D4 to /Video/CHRAM data buffer/CHRAM_D4.
Add net /Video/CHRAM data buffer/CHRAM_D3.
Reconnect U25 pin 15 from /VIdeo/CHRAM data buffer/CHRAM_D3 to /Video/CHRAM data buffer/CHRAM_D3.
Add net /Video/CHRAM data buffer/CHRAM_D2.
Reconnect U25 pin 13 from /VIdeo/CHRAM data buffer/CHRAM_D2 to /Video/CHRAM data buffer/CHRAM_D2.
Add net /Video/CHRAM data buffer/CHRAM_D1.
Reconnect U25 pin 12 from /VIdeo/CHRAM data buffer/CHRAM_D1 to /Video/CHRAM data buffer/CHRAM_D1.
Add net /Video/CHRAM data buffer/CHRAM_D0.
Reconnect U25 pin 11 from /VIdeo/CHRAM data buffer/CHRAM_D0 to /Video/CHRAM data buffer/CHRAM_D0.
Add net /Video/CHRAM_Adress_Mux/CHRAMA0.
Reconnect U25 pin 10 from /VIdeo/CHRAM_Adress_Mux/CHRAMA0 to /Video/CHRAM_Adress_Mux/CHRAMA0.
Add net /Video/CHRAM_Adress_Mux/CHRAMA1.
Reconnect U25 pin 9 from /VIdeo/CHRAM_Adress_Mux/CHRAMA1 to /Video/CHRAM_Adress_Mux/CHRAMA1.
Add net /Video/CHRAM_Adress_Mux/CHRAMA2.
Reconnect U25 pin 8 from /VIdeo/CHRAM_Adress_Mux/CHRAMA2 to /Video/CHRAM_Adress_Mux/CHRAMA2.
Add net /Video/CHRAM_Adress_Mux/CHRAMA3.
Reconnect U25 pin 7 from /VIdeo/CHRAM_Adress_Mux/CHRAMA3 to /Video/CHRAM_Adress_Mux/CHRAMA3.
Add net /Video/CHRAM_Adress_Mux/CHRAMA4.
Reconnect U25 pin 6 from /VIdeo/CHRAM_Adress_Mux/CHRAMA4 to /Video/CHRAM_Adress_Mux/CHRAMA4.
Add net /Video/CHRAM_Adress_Mux/CHRAMA5.
Reconnect U25 pin 5 from /VIdeo/CHRAM_Adress_Mux/CHRAMA5 to /Video/CHRAM_Adress_Mux/CHRAMA5.
Add net /Video/CHRAM_Adress_Mux/CHRAMA6.
Reconnect U25 pin 4 from /VIdeo/CHRAM_Adress_Mux/CHRAMA6 to /Video/CHRAM_Adress_Mux/CHRAMA6.
Add net /Video/CHRAM_Adress_Mux/CHRAMA7.
Reconnect U25 pin 3 from /VIdeo/CHRAM_Adress_Mux/CHRAMA7 to /Video/CHRAM_Adress_Mux/CHRAMA7.
Add net unconnected-(U26-I1d-Pad13).
Reconnect U26 pin 13 from /VIdeo/VRAM_Adress_Mux/CHARD7 to unconnected-(U26-I1d-Pad13).
Add net /Video/VRAM_Adress_Mux/VRAMA11.
Reconnect U26 pin 12 from /VIdeo/VRAM_Adress_Mux/CHRAMA11 to /Video/VRAM_Adress_Mux/VRAMA11.
Reconnect U26 pin 10 from /VIdeo/VRAM_Adress_Mux/CHARD6 to /Video/VRAM_Adress_Mux/MA10.
Add net /Video/VRAM_Adress_Mux/VRAMA10.
Reconnect U26 pin 9 from /VIdeo/VRAM_Adress_Mux/CHRAMA10 to /Video/VRAM_Adress_Mux/VRAMA10.
Add net /Video/VRAM_Adress_Mux/VRAMA9.
Reconnect U26 pin 7 from /VIdeo/VRAM_Adress_Mux/CHRAMA9 to /Video/VRAM_Adress_Mux/VRAMA9.
Reconnect U26 pin 6 from /VIdeo/VRAM_Adress_Mux/CHARD5 to /Video/VRAM_Adress_Mux/MA9.
Add net /Video/VRAM_Adress_Mux/VRAMA8.
Reconnect U26 pin 4 from /VIdeo/VRAM_Adress_Mux/CHRAMA8 to /Video/VRAM_Adress_Mux/VRAMA8.
Reconnect U26 pin 3 from /VIdeo/VRAM_Adress_Mux/CHARD4 to /Video/VRAM_Adress_Mux/MA8.
Add net /Video/Select Logic/~{VRAM_CS}.
Reconnect U26 pin 1 from /VIdeo/VRAM_Adress_Mux/~{CPU}/LATCH to /Video/Select Logic/~{VRAM_CS}.
Reconnect U27 pin 13 from /VIdeo/VRAM_Adress_Mux/CHARD3 to /Video/VRAM_Adress_Mux/MA7.
Add net /Video/VRAM_Adress_Mux/VRAMA7.
Reconnect U27 pin 12 from /VIdeo/VRAM_Adress_Mux/CHRAMA7 to /Video/VRAM_Adress_Mux/VRAMA7.
Reconnect U27 pin 10 from /VIdeo/VRAM_Adress_Mux/CHARD2 to /Video/VRAM_Adress_Mux/MA6.
Add net /Video/VRAM_Adress_Mux/VRAMA6.
Reconnect U27 pin 9 from /VIdeo/VRAM_Adress_Mux/CHRAMA6 to /Video/VRAM_Adress_Mux/VRAMA6.
Add net /Video/VRAM_Adress_Mux/VRAMA5.
Reconnect U27 pin 7 from /VIdeo/VRAM_Adress_Mux/CHRAMA5 to /Video/VRAM_Adress_Mux/VRAMA5.
Reconnect U27 pin 6 from /VIdeo/VRAM_Adress_Mux/CHARD1 to /Video/VRAM_Adress_Mux/MA5.
Add net /Video/VRAM_Adress_Mux/VRAMA4.
Reconnect U27 pin 4 from /VIdeo/VRAM_Adress_Mux/CHRAMA4 to /Video/VRAM_Adress_Mux/VRAMA4.
Reconnect U27 pin 3 from /VIdeo/VRAM_Adress_Mux/CHARD0 to /Video/VRAM_Adress_Mux/MA4.
Reconnect U27 pin 1 from /VIdeo/VRAM_Adress_Mux/~{CPU}/LATCH to /Video/Select Logic/~{VRAM_CS}.
Reconnect U28 pin 13 from /VIdeo/VRAM_Adress_Mux/RS3 to /Video/VRAM_Adress_Mux/MA3.
Add net /Video/VRAM_Adress_Mux/VRAMA3.
Reconnect U28 pin 12 from /VIdeo/VRAM_Adress_Mux/CHRAMA3 to /Video/VRAM_Adress_Mux/VRAMA3.
Reconnect U28 pin 10 from /VIdeo/VRAM_Adress_Mux/RS2 to /Video/VRAM_Adress_Mux/MA2.
Add net /Video/VRAM_Adress_Mux/VRAMA2.
Reconnect U28 pin 9 from /VIdeo/VRAM_Adress_Mux/CHRAMA2 to /Video/VRAM_Adress_Mux/VRAMA2.
Add net /Video/VRAM_Adress_Mux/VRAMA1.
Reconnect U28 pin 7 from /VIdeo/VRAM_Adress_Mux/CHRAMA1 to /Video/VRAM_Adress_Mux/VRAMA1.
Reconnect U28 pin 6 from /VIdeo/VRAM_Adress_Mux/RS1 to /Video/VRAM_Adress_Mux/MA1.
Add net /Video/VRAM_Adress_Mux/VRAMA0.
Reconnect U28 pin 4 from /VIdeo/VRAM_Adress_Mux/CHRAMA0 to /Video/VRAM_Adress_Mux/VRAMA0.
Reconnect U28 pin 3 from /VIdeo/VRAM_Adress_Mux/RS0 to /Video/VRAM_Adress_Mux/MA0.
Reconnect U28 pin 1 from /VIdeo/VRAM_Adress_Mux/~{CPU}/LATCH to /Video/Select Logic/~{VRAM_CS}.
Reconnect U29 pin 6 from /VIdeo/VID_CLK_GEN/CHR_CLK to /Video/VID_CLK_GEN/CHR_CLK.
Add U30 (footprint 'Package_SO:SOIC-14_3.9x8.7mm_P1.27mm').
Update U31 properties.
Add net /Video/CHRAM_Adress_Mux/~{CPU}/LATCH.
Reconnect U31 pin 13 from /VIdeo/CHRAM_Adress_Mux/~{CPU}/LATCH to /Video/CHRAM_Adress_Mux/~{CPU}/LATCH.
Add net /Video/CHRAM data buffer/~{CHRAM_RD}.
Reconnect U31 pin 11 from /VIdeo/CHRAM data buffer/~{CHRAM_RD} to /Video/CHRAM data buffer/~{CHRAM_RD}.
Reconnect U31 pin 9 from /VIdeo/CHRAM_Adress_Mux/~{CPU}/LATCH to /Video/CHRAM_Adress_Mux/~{CPU}/LATCH.
Add net /Video/CHRAM data buffer/~{CHRAM_WE}.
Reconnect U31 pin 8 from /VIdeo/CHRAM data buffer/~{CHRAM_WE} to /Video/CHRAM data buffer/~{CHRAM_WE}.
Add net /Video/Select Logic/~{VRAM_RD}.
Reconnect U31 pin 6 from /VIdeo/Select Logic/~{VRAM_RD} to /Video/Select Logic/~{VRAM_RD}.
Reconnect U31 pin 4 from /VIdeo/Select Logic/~{VRAM_CS} to /Video/Select Logic/~{VRAM_CS}.
Add net /Video/Select Logic/~{VRAM_WE}.
Reconnect U31 pin 3 from /VIdeo/Select Logic/~{VRAM_WE} to /Video/Select Logic/~{VRAM_WE}.
Reconnect U31 pin 2 from /VIdeo/Select Logic/~{VRAM_CS} to /Video/Select Logic/~{VRAM_CS}.
Reconnect U32 pin 8 from /VIdeo/Video Combination Logic/Composite vid/CSYNC to /Video/Video Combination Logic/Composite vid/CSYNC.
Add net /Video/VID_CLK_GEN/DOT_CLK.
Reconnect U32 pin 5 from /VIdeo/VID_CLK_GEN/DOT_CLK to /Video/VID_CLK_GEN/DOT_CLK.
Add net /Video/VID_CLK_GEN/~{CHR_CLK}.
Reconnect U32 pin 4 from /VIdeo/VID_CLK_GEN/~{CHR_CLK} to /Video/VID_CLK_GEN/~{CHR_CLK}.
Reconnect U32 pin 3 from /VIdeo/VID_CLK_GEN/CHR_CLK to /Video/VID_CLK_GEN/CHR_CLK.
Add U33 (footprint 'Package_SO:SOIC-16_3.9x9.9mm_P1.27mm').
Update U34 properties.
Reconnect U34 pin 27 from /VIdeo/Select Logic/~{VRAM_WE} to /Video/Select Logic/~{VRAM_WE}.
Add net /Video/VRAM_Adress_Mux/VRAMA13.
Reconnect U34 pin 26 from /VIdeo/VRAMA13 to /Video/VRAM_Adress_Mux/VRAMA13.
Reconnect U34 pin 25 from /VIdeo/VRAMA8 to /Video/VRAM_Adress_Mux/VRAMA8.
Reconnect U34 pin 24 from /VIdeo/VRAMA9 to /Video/VRAM_Adress_Mux/VRAMA9.
Reconnect U34 pin 23 from /VIdeo/VRAMA11 to /Video/VRAM_Adress_Mux/VRAMA11.
Reconnect U34 pin 21 from /VIdeo/VRAMA10 to /Video/VRAM_Adress_Mux/VRAMA10.
Add net /Video/VRAM data buffer/VRAM_D7.
Reconnect U34 pin 19 from /VIdeo/VRAM_D7 to /Video/VRAM data buffer/VRAM_D7.
Add net /Video/VRAM data buffer/VRAM_D6.
Reconnect U34 pin 18 from /VIdeo/VRAM_D6 to /Video/VRAM data buffer/VRAM_D6.
Add net /Video/VRAM data buffer/VRAM_D5.
Reconnect U34 pin 17 from /VIdeo/VRAM_D5 to /Video/VRAM data buffer/VRAM_D5.
Add net /Video/VRAM data buffer/VRAM_D4.
Reconnect U34 pin 16 from /VIdeo/VRAM_D4 to /Video/VRAM data buffer/VRAM_D4.
Add net /Video/VRAM data buffer/VRAM_D3.
Reconnect U34 pin 15 from /VIdeo/VRAM_D3 to /Video/VRAM data buffer/VRAM_D3.
Add net /Video/VRAM data buffer/VRAM_D2.
Reconnect U34 pin 13 from /VIdeo/VRAM_D2 to /Video/VRAM data buffer/VRAM_D2.
Add net /Video/VRAM data buffer/VRAM_D1.
Reconnect U34 pin 12 from /VIdeo/VRAM_D1 to /Video/VRAM data buffer/VRAM_D1.
Add net /Video/VRAM data buffer/VRAM_D0.
Reconnect U34 pin 11 from /VIdeo/VRAM_D0 to /Video/VRAM data buffer/VRAM_D0.
Reconnect U34 pin 10 from /VIdeo/VRAMA0 to /Video/VRAM_Adress_Mux/VRAMA0.
Reconnect U34 pin 9 from /VIdeo/VRAMA1 to /Video/VRAM_Adress_Mux/VRAMA1.
Reconnect U34 pin 8 from /VIdeo/VRAMA2 to /Video/VRAM_Adress_Mux/VRAMA2.
Reconnect U34 pin 7 from /VIdeo/VRAMA3 to /Video/VRAM_Adress_Mux/VRAMA3.
Reconnect U34 pin 6 from /VIdeo/VRAMA4 to /Video/VRAM_Adress_Mux/VRAMA4.
Reconnect U34 pin 5 from /VIdeo/VRAMA5 to /Video/VRAM_Adress_Mux/VRAMA5.
Reconnect U34 pin 4 from /VIdeo/VRAMA6 to /Video/VRAM_Adress_Mux/VRAMA6.
Reconnect U34 pin 3 from /VIdeo/VRAMA7 to /Video/VRAM_Adress_Mux/VRAMA7.
Add net /Video/VRAM_Adress_Mux/VRAMA12.
Reconnect U34 pin 2 from /VIdeo/VRAMA12 to /Video/VRAM_Adress_Mux/VRAMA12.
Reconnect U35 pin 19 from /VIdeo/VRAM data buffer/~{CHRAM_RD} to /Video/Select Logic/~{VRAM_RD}.
Reconnect U35 pin 18 from /VIdeo/VRAM data buffer/CHRAM_D0 to /Video/VRAM data buffer/VRAM_D0.
Reconnect U35 pin 17 from /VIdeo/VRAM data buffer/CHRAM_D0 to /Video/VRAM data buffer/VRAM_D0.
Reconnect U35 pin 16 from /VIdeo/VRAM data buffer/CHRAM_D1 to /Video/VRAM data buffer/VRAM_D1.
Reconnect U35 pin 15 from /VIdeo/VRAM data buffer/CHRAM_D1 to /Video/VRAM data buffer/VRAM_D1.
Reconnect U35 pin 14 from /VIdeo/VRAM data buffer/CHRAM_D2 to /Video/VRAM data buffer/VRAM_D2.
Reconnect U35 pin 13 from /VIdeo/VRAM data buffer/CHRAM_D2 to /Video/VRAM data buffer/VRAM_D2.
Reconnect U35 pin 12 from /VIdeo/VRAM data buffer/CHRAM_D3 to /Video/VRAM data buffer/VRAM_D3.
Reconnect U35 pin 11 from /VIdeo/VRAM data buffer/CHRAM_D3 to /Video/VRAM data buffer/VRAM_D3.
Reconnect U35 pin 3 from D0 to D3.
Reconnect U35 pin 2 from D0 to D3.
Reconnect U35 pin 1 from /VIdeo/VRAM data buffer/~{CHRAM_WE} to /Video/Select Logic/~{VRAM_WE}.
Reconnect U36 pin 19 from /VIdeo/VRAM data buffer/~{CHRAM_RD} to /Video/Select Logic/~{VRAM_RD}.
Reconnect U36 pin 18 from /VIdeo/VRAM data buffer/CHRAM_D4 to /Video/VRAM data buffer/VRAM_D4.
Reconnect U36 pin 17 from /VIdeo/VRAM data buffer/CHRAM_D4 to /Video/VRAM data buffer/VRAM_D4.
Reconnect U36 pin 16 from /VIdeo/VRAM data buffer/CHRAM_D5 to /Video/VRAM data buffer/VRAM_D5.
Reconnect U36 pin 15 from /VIdeo/VRAM data buffer/CHRAM_D5 to /Video/VRAM data buffer/VRAM_D5.
Reconnect U36 pin 14 from /VIdeo/VRAM data buffer/CHRAM_D6 to /Video/VRAM data buffer/VRAM_D6.
Reconnect U36 pin 13 from /VIdeo/VRAM data buffer/CHRAM_D6 to /Video/VRAM data buffer/VRAM_D6.
Reconnect U36 pin 12 from /VIdeo/VRAM data buffer/CHRAM_D7 to /Video/VRAM data buffer/VRAM_D7.
Reconnect U36 pin 11 from /VIdeo/VRAM data buffer/CHRAM_D7 to /Video/VRAM data buffer/VRAM_D7.
Reconnect U36 pin 1 from /VIdeo/VRAM data buffer/~{CHRAM_WE} to /Video/Select Logic/~{VRAM_WE}.
Update U37 properties.
Add net /Video/CHRAM_Adress_Mux/CHARD0.
Reconnect U37 pin 19 from /VIdeo/CHRAM_Adress_Mux/CHARD0 to /Video/CHRAM_Adress_Mux/CHARD0.
Add net /Video/CHRAM_Adress_Mux/CHARD1.
Reconnect U37 pin 18 from /VIdeo/CHRAM_Adress_Mux/CHARD1 to /Video/CHRAM_Adress_Mux/CHARD1.
Add net /Video/CHRAM_Adress_Mux/CHARD2.
Reconnect U37 pin 17 from /VIdeo/CHRAM_Adress_Mux/CHARD2 to /Video/CHRAM_Adress_Mux/CHARD2.
Add net /Video/CHRAM_Adress_Mux/CHARD3.
Reconnect U37 pin 16 from /VIdeo/CHRAM_Adress_Mux/CHARD3 to /Video/CHRAM_Adress_Mux/CHARD3.
Add net /Video/CHRAM_Adress_Mux/CHARD4.
Reconnect U37 pin 15 from /VIdeo/CHRAM_Adress_Mux/CHARD4 to /Video/CHRAM_Adress_Mux/CHARD4.
Add net /Video/CHRAM_Adress_Mux/CHARD5.
Reconnect U37 pin 14 from /VIdeo/CHRAM_Adress_Mux/CHARD5 to /Video/CHRAM_Adress_Mux/CHARD5.
Add net /Video/CHRAM_Adress_Mux/CHARD6.
Reconnect U37 pin 13 from /VIdeo/CHRAM_Adress_Mux/CHARD6 to /Video/CHRAM_Adress_Mux/CHARD6.
Add net /Video/CHRAM_Adress_Mux/CHARD7.
Reconnect U37 pin 12 from /VIdeo/CHRAM_Adress_Mux/CHARD7 to /Video/CHRAM_Adress_Mux/CHARD7.
Reconnect U37 pin 9 from /VIdeo/VRAM_D7 to /Video/VRAM data buffer/VRAM_D7.
Reconnect U37 pin 8 from /VIdeo/VRAM_D6 to /Video/VRAM data buffer/VRAM_D6.
Reconnect U37 pin 7 from /VIdeo/VRAM_D5 to /Video/VRAM data buffer/VRAM_D5.
Reconnect U37 pin 6 from /VIdeo/VRAM_D4 to /Video/VRAM data buffer/VRAM_D4.
Reconnect U37 pin 5 from /VIdeo/VRAM_D3 to /Video/VRAM data buffer/VRAM_D3.
Reconnect U37 pin 4 from /VIdeo/VRAM_D2 to /Video/VRAM data buffer/VRAM_D2.
Reconnect U37 pin 3 from /VIdeo/VRAM_D1 to /Video/VRAM data buffer/VRAM_D1.
Reconnect U37 pin 2 from /VIdeo/VRAM_D0 to /Video/VRAM data buffer/VRAM_D0.
Update U38 properties.
Reconnect U38 pin 14 from /VIdeo/CHRAM data buffer/CHRAM_D3 to /Video/CHRAM data buffer/CHRAM_D3.
Reconnect U38 pin 13 from /VIdeo/CHRAM data buffer/CHRAM_D2 to /Video/CHRAM data buffer/CHRAM_D2.
Reconnect U38 pin 12 from /VIdeo/CHRAM data buffer/CHRAM_D1 to /Video/CHRAM data buffer/CHRAM_D1.
Reconnect U38 pin 11 from /VIdeo/CHRAM data buffer/CHRAM_D0 to /Video/CHRAM data buffer/CHRAM_D0.
Reconnect U38 pin 9 from /VIdeo/Video Combination Logic/DOT_OUT to /Video/Video Combination Logic/DOT_OUT.
Reconnect U38 pin 6 from /VIdeo/CHRAM data buffer/CHRAM_D7 to /Video/CHRAM data buffer/CHRAM_D7.
Reconnect U38 pin 5 from /VIdeo/CHRAM data buffer/CHRAM_D6 to /Video/CHRAM data buffer/CHRAM_D6.
Reconnect U38 pin 4 from /VIdeo/CHRAM data buffer/CHRAM_D5 to /Video/CHRAM data buffer/CHRAM_D5.
Reconnect U38 pin 3 from /VIdeo/CHRAM data buffer/CHRAM_D4 to /Video/CHRAM data buffer/CHRAM_D4.
Reconnect U38 pin 2 from /VIdeo/VID_CLK_GEN/DOT_CLK to /Video/VID_CLK_GEN/DOT_CLK.
Reconnect U38 pin 1 from /VIdeo/VID_CLK_GEN/CHR_CLK to /Video/VID_CLK_GEN/CHR_CLK.
Update U39 properties.
Reconnect U39 pin 13 from /VIdeo/CHRAM_Adress_Mux/CHARD7 to /Video/CHRAM_Adress_Mux/CHARD7.
Reconnect U39 pin 12 from /VIdeo/CHRAM_Adress_Mux/CHRAMA11 to /Video/CHRAM_Adress_Mux/CHRAMA11.
Reconnect U39 pin 10 from /VIdeo/CHRAM_Adress_Mux/CHARD6 to /Video/CHRAM_Adress_Mux/CHARD6.
Reconnect U39 pin 9 from /VIdeo/CHRAM_Adress_Mux/CHRAMA10 to /Video/CHRAM_Adress_Mux/CHRAMA10.
Reconnect U39 pin 7 from /VIdeo/CHRAM_Adress_Mux/CHRAMA9 to /Video/CHRAM_Adress_Mux/CHRAMA9.
Reconnect U39 pin 6 from /VIdeo/CHRAM_Adress_Mux/CHARD5 to /Video/CHRAM_Adress_Mux/CHARD5.
Reconnect U39 pin 4 from /VIdeo/CHRAM_Adress_Mux/CHRAMA8 to /Video/CHRAM_Adress_Mux/CHRAMA8.
Reconnect U39 pin 3 from /VIdeo/CHRAM_Adress_Mux/CHARD4 to /Video/CHRAM_Adress_Mux/CHARD4.
Reconnect U39 pin 1 from /VIdeo/CHRAM_Adress_Mux/~{CPU}/LATCH to /Video/CHRAM_Adress_Mux/~{CPU}/LATCH.
Update U40 properties.
Reconnect U40 pin 13 from /VIdeo/CHRAM_Adress_Mux/CHARD3 to /Video/CHRAM_Adress_Mux/CHARD3.
Reconnect U40 pin 12 from /VIdeo/CHRAM_Adress_Mux/CHRAMA7 to /Video/CHRAM_Adress_Mux/CHRAMA7.
Reconnect U40 pin 10 from /VIdeo/CHRAM_Adress_Mux/CHARD2 to /Video/CHRAM_Adress_Mux/CHARD2.
Reconnect U40 pin 9 from /VIdeo/CHRAM_Adress_Mux/CHRAMA6 to /Video/CHRAM_Adress_Mux/CHRAMA6.
Reconnect U40 pin 7 from /VIdeo/CHRAM_Adress_Mux/CHRAMA5 to /Video/CHRAM_Adress_Mux/CHRAMA5.
Reconnect U40 pin 6 from /VIdeo/CHRAM_Adress_Mux/CHARD1 to /Video/CHRAM_Adress_Mux/CHARD1.
Reconnect U40 pin 4 from /VIdeo/CHRAM_Adress_Mux/CHRAMA4 to /Video/CHRAM_Adress_Mux/CHRAMA4.
Reconnect U40 pin 3 from /VIdeo/CHRAM_Adress_Mux/CHARD0 to /Video/CHRAM_Adress_Mux/CHARD0.
Reconnect U40 pin 1 from /VIdeo/CHRAM_Adress_Mux/~{CPU}/LATCH to /Video/CHRAM_Adress_Mux/~{CPU}/LATCH.
Change C2 footprint from 'Capacitor_SMD:C_0603_1608Metric_Pad1.08x0.95mm_HandSolder' to 'Capacitor_SMD:C_0805_2012Metric_Pad1.18x1.45mm_HandSolder'.
Update U41 properties.
Reconnect U41 pin 13 from /VIdeo/CHRAM_Adress_Mux/RS3 to /Video/CHRAM_Adress_Mux/RS3.
Reconnect U41 pin 12 from /VIdeo/CHRAM_Adress_Mux/CHRAMA3 to /Video/CHRAM_Adress_Mux/CHRAMA3.
Reconnect U41 pin 10 from /VIdeo/CHRAM_Adress_Mux/RS2 to /Video/CHRAM_Adress_Mux/RS2.
Reconnect U41 pin 9 from /VIdeo/CHRAM_Adress_Mux/CHRAMA2 to /Video/CHRAM_Adress_Mux/CHRAMA2.
Reconnect U41 pin 7 from /VIdeo/CHRAM_Adress_Mux/CHRAMA1 to /Video/CHRAM_Adress_Mux/CHRAMA1.
Reconnect U41 pin 6 from /VIdeo/CHRAM_Adress_Mux/RS1 to /Video/CHRAM_Adress_Mux/RS1.
Reconnect U41 pin 4 from /VIdeo/CHRAM_Adress_Mux/CHRAMA0 to /Video/CHRAM_Adress_Mux/CHRAMA0.
Reconnect U41 pin 3 from /VIdeo/CHRAM_Adress_Mux/RS0 to /Video/CHRAM_Adress_Mux/RS0.
Reconnect U41 pin 1 from /VIdeo/CHRAM_Adress_Mux/~{CPU}/LATCH to /Video/CHRAM_Adress_Mux/~{CPU}/LATCH.
Change C3 footprint from 'Capacitor_SMD:C_0603_1608Metric_Pad1.08x0.95mm_HandSolder' to 'Capacitor_SMD:C_0805_2012Metric_Pad1.18x1.45mm_HandSolder'.
Update U42 properties.
Reconnect U42 pin 19 from /VIdeo/CHRAM data buffer/~{CHRAM_RD} to /Video/CHRAM data buffer/~{CHRAM_RD}.
Reconnect U42 pin 18 from /VIdeo/CHRAM data buffer/CHRAM_D0 to /Video/CHRAM data buffer/CHRAM_D0.
Reconnect U42 pin 17 from /VIdeo/CHRAM data buffer/CHRAM_D0 to /Video/CHRAM data buffer/CHRAM_D0.
Reconnect U42 pin 16 from /VIdeo/CHRAM data buffer/CHRAM_D1 to /Video/CHRAM data buffer/CHRAM_D1.
Reconnect U42 pin 15 from /VIdeo/CHRAM data buffer/CHRAM_D1 to /Video/CHRAM data buffer/CHRAM_D1.
Reconnect U42 pin 14 from /VIdeo/CHRAM data buffer/CHRAM_D2 to /Video/CHRAM data buffer/CHRAM_D2.
Reconnect U42 pin 13 from /VIdeo/CHRAM data buffer/CHRAM_D2 to /Video/CHRAM data buffer/CHRAM_D2.
Reconnect U42 pin 12 from /VIdeo/CHRAM data buffer/CHRAM_D3 to /Video/CHRAM data buffer/CHRAM_D3.
Reconnect U42 pin 11 from /VIdeo/CHRAM data buffer/CHRAM_D3 to /Video/CHRAM data buffer/CHRAM_D3.
Reconnect U42 pin 3 from D0 to D3.
Reconnect U42 pin 2 from D0 to D3.
Reconnect U42 pin 1 from /VIdeo/CHRAM data buffer/~{CHRAM_WE} to /Video/CHRAM data buffer/~{CHRAM_WE}.
Change C4 footprint from 'Capacitor_SMD:C_0603_1608Metric_Pad1.08x0.95mm_HandSolder' to 'Capacitor_SMD:C_0805_2012Metric_Pad1.18x1.45mm_HandSolder'.
Update U43 properties.
Reconnect U43 pin 19 from /VIdeo/CHRAM data buffer/~{CHRAM_RD} to /Video/CHRAM data buffer/~{CHRAM_RD}.
Reconnect U43 pin 18 from /VIdeo/CHRAM data buffer/CHRAM_D4 to /Video/CHRAM data buffer/CHRAM_D4.
Reconnect U43 pin 17 from /VIdeo/CHRAM data buffer/CHRAM_D4 to /Video/CHRAM data buffer/CHRAM_D4.
Reconnect U43 pin 16 from /VIdeo/CHRAM data buffer/CHRAM_D5 to /Video/CHRAM data buffer/CHRAM_D5.
Reconnect U43 pin 15 from /VIdeo/CHRAM data buffer/CHRAM_D5 to /Video/CHRAM data buffer/CHRAM_D5.
Reconnect U43 pin 14 from /VIdeo/CHRAM data buffer/CHRAM_D6 to /Video/CHRAM data buffer/CHRAM_D6.
Reconnect U43 pin 13 from /VIdeo/CHRAM data buffer/CHRAM_D6 to /Video/CHRAM data buffer/CHRAM_D6.
Reconnect U43 pin 12 from /VIdeo/CHRAM data buffer/CHRAM_D7 to /Video/CHRAM data buffer/CHRAM_D7.
Reconnect U43 pin 11 from /VIdeo/CHRAM data buffer/CHRAM_D7 to /Video/CHRAM data buffer/CHRAM_D7.
Reconnect U43 pin 1 from /VIdeo/CHRAM data buffer/~{CHRAM_WE} to /Video/CHRAM data buffer/~{CHRAM_WE}.
Add C8 (footprint 'Capacitor_SMD:C_0603_1608Metric_Pad1.08x0.95mm_HandSolder').
Reconnect U44 pin 2 from /VIdeo/VID_CLK_GEN/DOT_CLK to /Video/VID_CLK_GEN/DOT_CLK.
Reconnect U44 pin 1 from /VIdeo/VID_CLK_GEN/~{CHR_CLK} to /Video/VID_CLK_GEN/~{CHR_CLK}.
Add C9 (footprint 'Capacitor_SMD:C_0603_1608Metric_Pad1.08x0.95mm_HandSolder').
Reconnect U45 pin 9 from /VIdeo/VID_CLK_GEN/DOT_CLK to /Video/VID_CLK_GEN/DOT_CLK.
Reconnect U45 pin 3 from /VIdeo/Video Combination Logic/CURSOR to /Video/Video Combination Logic/CURSOR.
Add C10 (footprint 'Capacitor_SMD:C_0603_1608Metric_Pad1.08x0.95mm_HandSolder').
Reconnect U46 pin 5 from /VIdeo/Video Combination Logic/Composite vid/Y to /Video/Video Combination Logic/Composite vid/Y.
Add C11 (footprint 'Capacitor_SMD:C_0603_1608Metric_Pad1.08x0.95mm_HandSolder').
Add C12 (footprint 'Capacitor_SMD:C_0603_1608Metric_Pad1.08x0.95mm_HandSolder').
Add C13 (footprint 'Capacitor_SMD:C_0603_1608Metric_Pad1.08x0.95mm_HandSolder').
Add C14 (footprint 'Capacitor_SMD:C_0603_1608Metric_Pad1.08x0.95mm_HandSolder').
Reconnect X1 pin 3 from /VIdeo/VID_CLK_GEN/DOT_CLK to /Video/VID_CLK_GEN/DOT_CLK.
Add C15 (footprint 'Capacitor_SMD:C_0603_1608Metric_Pad1.08x0.95mm_HandSolder').
Add C16 (footprint 'Capacitor_SMD:C_0603_1608Metric_Pad1.08x0.95mm_HandSolder').
Warning: No net found for symbol U25 pin 1.
Warning: No net found for symbol J4 pin MH2.
Warning: No net found for symbol U17 pin 6.
Warning: No net found for symbol J4 pin MH1.
Warning: No net found for symbol U17 pin 13.
Warning: No net found for symbol U17 pin 25.
Warning: No net found for symbol J2 pin MH2.
Warning: No net found for symbol J5 pin MH1.
Warning: No net found for symbol U17 pin 1.
Warning: No net found for symbol J5 pin MH2.
Warning: No net found for symbol U46 pin 14.
Warning: No net found for symbol U46 pin 7.
Warning: No net found for symbol U17 pin 36.
Warning: No net found for symbol U17 pin 48.
Warning: No net found for symbol U32 pin 14.
Warning: No net found for symbol J2 pin MH1.
Warning: No net found for symbol U17 pin 21.
Warning: No net found for symbol U32 pin 7.
Warning: No net found for symbol U17 pin 37.
Warning: No net found for symbol Y1 pin 3.
Warning: No net found for symbol Y1 pin 3.
Warning: No net found for symbol Y1 pin 3.
Error: Cannot add C50 (no footprint assigned).
Error: Cannot add C49 (no footprint assigned).

Info: Total warnings: 22, errors: 2.

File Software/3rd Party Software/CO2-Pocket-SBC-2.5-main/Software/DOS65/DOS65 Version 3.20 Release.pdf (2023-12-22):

## DOS/65 Version 3.20 Release: 4th April, 2023 By Kevin E. Maier

This release is based on DOS/65 Version 3.0, written by Richard A. Leary. There is still large core of Richard’s original code in this release, but there’s a large number of changes, including certain routines which have been replaced, re-written and in some cases, removed. There are also major changes in the way disk drives are accessed.

Richard’s code was essentially a port of CP/M from the Intel 8080 over to the 6502 (original NMOS CPU). The intent was to provide a standard CP/M-like operating environment on the 6502 that had a common filesystem format and system calls. While this would not provide a binary level of compatibility with CP/M, it would provide a common code structure and compatibility at a disk level.

DOS/65 has been licensed code directly from Richard for many years. The last version that Richard worked on (to the best of my knowledge) was Version 3.0. There are two versions of the 3.0 code: A RAM based, bootable version (using SYSGEN) and a ROM based version. These final versions did provide some additional features and functions beyond the previous 2.1 version, which are highlighted below:

- A CP/M compatible User area for storage devices is now supported
- A CP/M compatible SUBMIT batch processing capability is added to CCM
- The IOSTAT variable now provides the USER number and Drive number

There are some functional limitations of DOS/65, which are highlighted below:

- A maximum of 8 drives (drive letters A – H) are supported
- Each allocated drive is limited to 8MB total size
- A single file has a maximum size of 512KB

In the DOS65 V3.0A Supplement Rev A (March 2021), Richard changed the license agreement for the 3.0 ROM Version as shown below:

“The DOS/65 V3 ROM software and all other DOS/65 software are free software; you can redistribute it and/or modify it under the terms of the GNU General Public License as published by the Free Software Foundation; either version 3 of the license, or any later version.”

My (personal) view is that Richard has stopped supporting and updating DOS/65, hence the change in the licensing to GNU GPL Version 3 or later. By referencing “all other DOS/65 software”, this should include earlier releases and the accompanying utility programs, most of which were released under Version 2.x . This would include applications like the Assembler, Basic Compiler, Runtime for the Compiler, Editor, etc. If anyone has knowledge that this is not the case, please let me know by email (address below). My last correspondence with Richard was around the end of 2021. Hans Otten did exchange some correspondence with him in 2022. Based on this, Hans has provided some details and links on his website for DOS/65 here:

http://retro.hansotten.nl/6502-sbc/dos-65/

There have also been multiple threads and discussion on 6502.ORG and some other sites which Richard participated in directly for older systems such as the OSI, which can be found here:

http://osiweb.org/osiforum/viewtopic.php?f=4&t=235&start=40

I started working with DOS/65 back in 2021 and have made numerous changes and updates to CCM, PEM and modified a SIM module to interface to the BIOS of my C02 Pocket SBC with the Compact-Flash and RTC adapter. This was a ROM based version and was smaller and a bit faster than the original ROM code from Richard.

I started working on a RAM based version which is bootable from disk in late 2022, which would allow for a larger RAM space and reduced ROM footprint. There are many significant changes with this new version. Some of these are highlighted below:

- Separation of CCM, PEM and SIM into standalone modules
- Rewriting CCM/PEM modules to take advantage of CMOS opcodes and addressing modes
- Fixing a few problem areas for drive letters and out of range inputs to CCM/PEM
- Elimination of Track/Sector based disk accesses – all disk access is Record based
- Elimination of Checksum routines in PEM, used for diskette-based media
- Elimination of all code that supports removable media (e.g., diskettes)
- Update to the Disk Control Block (DCB) for Record Based media
- A completely new SIM module with enhanced blocking/de-blocking
- Source code ported to WDC Tools for assembly/linking
- Version 2.1 utilities are still fully compatible (Assembler, Editor, Basic, etc.)
- Updates to some core utilities such as SD to accommodate the updated DCB (more in the works)

The above work has resulted in smaller CCM and PEM modules, which can run on any CMOS processor. Many of the changes to PEM calls are specific to disk-based access routines. Using the updated DCB, Record calls to SIM also include Reserved Records per the DCB which are passed over to SIM. The Reserved Tracks call to SIM is no longer used, as PEM will add the offset for Reserved Records per drive when calling SIM. Also note that the PEM call to translate sectors (diskette only) is now considered obsolete and simply returns, doing nothing. The Home Drive SIM call is also obsolete due to non-removable media. The DCB has been modified slightly to reflect Reserved Records, not Tracks, and eliminates the last 3 bytes which define the checksum enable byte and the checksum map address. These calls are no longer necessary as supported storage devices are all LBA based and non-removable. This can include any standard media such as IDE, Compact Flash (in IDE mode), SCSI block devices and newer devices such as SD-Card. In short, any media that can be interfaced to a 65C02 system and addressed via LBA access can be supported with a compatible BIOS that SIM can interface with.

With rare exception, any existing application for DOS/65 should run without changes. To date, I’ve assembled and tested almost every utility that was provided with DOS/65 Version 2.1 and 3.0. Of course, there are certain applications/utilities that are specific to the hardware platform, such as DEBUG, that need to be customized for the hardware being used. As my particular system already has a high function Monitor, I’ve opted to not make changes to the DOS/65 DEBUG program. I also have no plans on updating it, as I don’t need it for my 65C02 system(s). If anyone else chooses to use this new DOS/65 version (3.20), they might want to consider updating the DEBUG program to use with their system.

The hardware system I have used to develop and test the new version on is my C02 Pocket SBC prototype system, which is described below:

- W65C02 Processor running at 8MHz
- AT28BV256 EEPROM addressed from $E000 - $FFFF (8KB)
- Alliance 128KB SRAM addressed from $0000 - $DFFF (56KB)
- I/O Window configured at $FE00 – 5 I/O selects, each at 32-bytes wide
- NXP SC28L92 DUART – both ports and timer configured
- Maxim DS15x1 RTC clock (not used with DOS/65 currently)
- Hitachi 6GB Microdrive PATA ZIF with 16-bit IDE interface
- TL7733 Reset Supervisor and DS1233A for NMI Panic trigger
- BIOS supports DUART and Microdrive via interrupt-driven code
- BIOS Jump table at $FF00 is called by SIM for hardware access
- All hardware is now 3.3 Volt only (Microdrive is only 3.3V power)

DOS/65 Version 3.20 requires 5KB of memory for CCM, PEM and their associated Data areas. The SIM module is mapped to 1KB of memory after PEM, but currently only uses 768 bytes. All modules are mapped to page boundaries. There are 9 pages for CCM, 11 pages for PEM and 4 pages allocated for SIM. This totals to 6KB of RAM and the default storage configuration provides for eight drives, each at 8MB size. The drives are configured as:

- 4096 total blocks
- 2048 bytes block size
- 1024 directory entries per drive
- 4 Records per Disk Block

The additional 4KB for allocation maps brings the total DOS/65 size to 10KB. Note that the C02 Pocket SBC prototype uses the first 2KB for hardware support: Page Zero, Stack, Software Vectors, Serial and Disk buffers. The upper 8KB is mapped as ROM and contains a rich function Monitor, the BIOS and the I/O mapping. Loading from the Reserved Records area of the first drive, DOS/65 is loaded starting at $B800 and the TEA starts at $0800. This provides 44KB of free memory for user programs, with an additional 2.25KB by overwriting CCM if required.

It is possible to reduce the ROM size by shrinking or eliminating the Monitor code, which could increase RAM by roughly 6KB. Note however that the Monitor does have some useful code which can help with debugging and benchmarking. It also allows full examination and modification of memory, including a disassembler and a XMODEM-CRC utility with S19 record support. Currently, the C02 BIOS allocates the upper 48 bytes of Page Zero (2 bytes are free) and the C02 Monitor allocates 48 bytes of Page Zero directly below the BIOS (1 byte is free). DOS/65 Version 3.20, which is RAM based only uses 8 bytes of Page Zero space. This provides 152 bytes of contiguous Page Zero space for user applications. It’s also possible for user applications to use some of the Monitor’s Page Zero space if required.

To date, extensive testing has been done on the current Version 3.20 final release, which includes extensive disk activity with utility applications including:

- SUBMIT
- Assembler
- MakeCom
- Alloc
- SD (Super Directory)
- Basic Compiler and Runtime
- COPY and UCOPY
- COMPARE
- DUMP
- MORE
- PAGE
- XMODEM

The 3.3-volt hardware system has been completely stable without any crashes, running for months non-stop. The 3.20 release level of DOS/65 has also been completely stable without any crashes. The code has been exercised extensively with “sub” files that copy files from drive to drive, compare files from drive to drive, build the entire toolset of utilities, Xmodem uploads/downloads, etc. There simply have been no failures as of yet (all fingers crossed).

CCM and PEM now check for disk drive ranges and show an “UNKNOWN DRIVE” error if the attempted drive is out of the range of the system. Furthermore, there are no longer any possible phantom drive access issues (e.g., trying to access drive t:, or even a non-alpha character), which could cause disk problems if inadvertently used from CCM or a call to PEM. Note however that many of the existing utility programs do not properly test for drive letters that the user can enter. In general, these utilities simply mask off the lower 3-bits for the drive letter. Over time, I will start to work on these utilities so they are updated to properly handle out of range drives. Other application/utility issues are a lack of a consistent exit to DOS when finished. Some applications/utilities return to DOS from a RTS, while others exit by a Warm Boot to PEM, which is preferred.

The new SIM module manages blocking and de-blocking for reading and writing blocks to the disk. SIM keeps track of the current 512-byte disk block buffer and matches it to the Record number requested by PEM for reading and writing. SIM also provides a performance enhancement to Record reads and writes. A single disk flag byte provides separate flags for read and write operations in progress, a valid LBA loaded, with a Dirty Block flag for delayed writes and the 2-bit Record offset within the currently loaded LBA. This has resulted in very good overall performance and a smaller SIM memory footprint. Note that PEM no longer needs, or uses, a “write type” when calling SIM for disk writes and the associated (PEM) code has been removed.

With Version 3.20, there is no SYSGEN level of system creation. WDC Tools are used for assembling CCM, PEM and SIM, with the linked output as a Motorola S-Record (S19) file. The C02 Monitor supports downloading via XMODEM-CRC of S-records, which can quickly download the complete DOS/65 Image. I’ve written a disk utility that provides a fair amount of function for testing and examining an IDE device. A recently added function is to write a section of memory to a contiguous set of blocks on the IDE device. As the C02 Pocket SBC is using a disk partitioning scheme to provide multiple bootable partitions, a partition offset is added to SIM which defines the starting LBA for all of its drives. The actual utilities to setup the storage device and configure the partition and boot records is still a work in progress. For the time being, the C02 Monitor simply loads the image from the drive to memory and jumps to the cold-start address for SIM. The warm-boot code in SIM reloads CCM and PEM from the reserved section of the first drive.

Any system which has a bootable disk feature should be able to boot this version of DOS/65, but will require some minimal changes to the SIM module to interface to the local machine BIOS.

I’m hoping some others can take advantage of this new version of DOS/65 and get it running on a wider range of 65C02 systems. The only functions required to implement this are a compatible BIOS to support the console and disk-based calls. This has been a fun project and many thanks to Richard for his time and effort to provide DOS/65 to the 6502 community.

Best Regards, KM
kemaier2@bellsouth.net
https://github.com/floobydust

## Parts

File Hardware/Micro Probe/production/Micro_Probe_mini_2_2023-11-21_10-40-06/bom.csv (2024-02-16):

Designator | Footprint | Quantity | Value | LCSC Part #
C1, C10, C11, C12, C13, C14, C15, C16, C17, C18, C19, C2, C20, C21, C22, C23, C24, C25, C26, C27, C28, C29, C3, C30, C31, C32, C33, C34, C35, C36, C37, C38, C39, C4, C40, C41, C42, C43, C44, C45, C46, C47, C48, C49, C5, C50, C51, C6, C7, C8, C9 | 0603 | 51 | 8.2pF
J1 | PinHeader_2x20_P2.54mm_Vertical | 1 | Conn_02x20_Counter_Clockwise
J2 | PinHeader_2x20_P2.54mm_Vertical | 1 | ADDRESS
J3 | PinHeader_2x20_P2.54mm_Vertical | 1 | DATA/CONTROL
J4 | PinHeader_2x20_P2.54mm_Vertical | 1 | BANK SELECT/MISC
J5 | JST_SH_SM08B-SRSS-TB_1x08-1MP_P1.00mm_Horizontal | 1 | BANK SELECT
J6 | JST_SH_SM08B-SRSS-TB_1x08-1MP_P1.00mm_Horizontal | 1 | MISC
J7, J8 | JST_SH_SM02B-SRSS-TB_1x02-1MP_P1.00mm_Horizontal | 2 | CLK2
R1, R101, R11, R13, R15, R17, R19, R21, R23, R25, R27, R29, R3, R31, R33, R35, R37, R39, R41, R43, R45, R47, R49, R5, R51, R53, R55, R57, R59, R61, R63, R65, R67, R69, R7, R71, R73, R75, R77, R79, R81, R83, R85, R87, R89, R9, R91, R93, R95, R97, R99 | 0603 | 51 | 90.9k
R10, R100, R102, R12, R14, R16, R18, R2, R20, R22, R24, R26, R28, R30, R32, R34, R36, R38, R4, R40, R42, R44, R46, R48, R50, R52, R54, R56, R58, R6, R60, R62, R64, R66, R68, R70, R72, R74, R76, R78, R8, R80, R82, R84, R86, R88, R90, R92, R94, R96, R98 | 0603 | 51 | 250R
mouse-bite-2mm-slot_5, mouse-bite-2mm-slot_4, mouse-bite-2mm-slot_3, mouse-bite-2mm-slot_2, mouse-bite-2mm-slot | mouse-bite-2mm-slot | 5 | VAL**

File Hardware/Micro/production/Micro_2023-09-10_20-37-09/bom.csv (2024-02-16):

Designator | Footprint | Quantity | Value | LCSC Part #
C1 | 0603 | 1 | 47nF
C2, C3, C4 | 0603 | 3 | 330nF
C5 | 0603 | 1 | 22pF
C6 | 0603 | 1 | 47pF
C7 | 0603 | 1 | 100nF
D1, D2, D3 | D_SOD-123 | 3 | 1N4148W
J1 | DIP-16_W7.62mm_Socket | 1 | Keyboard Connector
J2, J4, J5 | L717SDE09PA4CH3F | 3 | DE9_Plug_MountingHoles
J3 | 1560099E | 1 | 156-0099-E
J6 | PinSocket_1x14_P2.54mm_Vertical | 1 | GPI/O
J7, J8 | PinSocket_1x10_P2.54mm_Vertical | 2 | Conn_01x10
JP1 | SolderJumper-3_P1.3mm_Open_Pad1.0x1.5mm_NumberLabels | 1 | ASCII D7
JP10 | SolderJumper-3_P1.3mm_Open_Pad1.0x1.5mm_NumberLabels | 1 | Timer_IRQ
JP2, JP3, JP4, JP5, JP6, JP7, JP8, JP9 | SolderJumper-2_P1.3mm_Open_RoundedPad1.0x1.5mm | 8 | SolderJumper_2_Open
Q4 | SOT-23_Handsoldering | 1 | MMBT3904
R1, R2, R3 | 0603 | 3 | 2.2K
R10 | 0603 | 1 | 150R
R11 | 0603 | 1 | 200R
R4 | 0603 | 1 | 4.7k
R5, R7 | 0603 | 2 | 1.5k
R6 | 0603 | 1 | 1M
R8 | 0603 | 1 | 2K
R9 | 0603 | 1 | 10R
U1 | MQFP-44_10x10mm_P0.8mm | 1 | W65C02SxQ
U10, U11 | SOIC-24W_7.5x15.4mm_P1.27mm | 2 | 74HC154
U12, U15, U23 | SOIC-20W_7.5x12.8mm_P1.27mm | 3 | 74HC373
U13, U21, U7 | SOIC-14_3.9x8.7mm_P1.27mm | 3 | 74HC02
U14 | PLCC-28 | 1 | 82C54_PLCC
U16, U22, U30 | SOIC-14_3.9x8.7mm_P1.27mm | 3 | 74HC32
U17 | TQFP-48_7x7mm_P0.5mm | 1 | TL16C550D/DL PT/PFB
U18 | TSSOP-28_4.4x9.7mm_P0.65mm | 1 | TRSF3243
U19 | SOIC-14_3.9x8.7mm_P1.27mm | 1 | 74HC86
U2 | SOIC-28W_7.5x17.9mm_P1.27mm | 1 | AT28HC64BF
U20 | PLCC-44 | 1 | W65C21SxPL
U24 | DIP-40_W15.24mm | 1 | 6545
U25 | SOIC-28W_7.5x18.7mm_P1.27mm | 1 | AS6C6264
U26, U27, U28, U39, U40, U41, U47, U48 | SOIC-16_3.9x9.9mm_P1.27mm | 8 | 74HC157
U29, U31, U49, U8, U9 | SOIC-14_3.9x8.7mm_P1.27mm | 5 | 74HC08
U3, U34 | SOIC-28W_7.5x17.9mm_P1.27mm | 2 | IS62C256AL
U32 | SOIC-14_3.9x8.7mm_P1.27mm | 1 | 74HC04
U35, U36, U42, U43 | SOIC-20W_7.5x12.8mm_P1.27mm | 4 | 74HC244
U37 | SOIC-20W_7.5x12.8mm_P1.27mm | 1 | 74HC574
U38 | SOIC-16_3.9x9.9mm_P1.27mm | 1 | 74HC165
U4, U5, U6 | SOIC-14_3.9x8.7mm_P1.27mm | 3 | 74HC00
U44 | SOIC-16_3.9x9.9mm_P1.27mm | 1 | 74HC163
U45 | SOIC-16_3.9x9.9mm_P1.27mm | 1 | 74HC174
U46 | SOIC-14_3.9x8.7mm_P1.27mm | 1 | 74HC74
X1 | Oscillator_SMD_Fordahl_DFAS11-4Pin_7.0x5.0mm | 1 | DFA-S11
X2 | Oscillator_SMD_Abracon_ASV-4Pin_7.0x5.1mm_HandSoldering | 1 | ASV-2.5MHz
Y1 | Crystal_HC49-U_Horizontal_1EP_style2 | 1 | 1.8432MHz

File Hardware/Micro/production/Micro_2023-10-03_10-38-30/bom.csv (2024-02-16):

Designator | Footprint | Quantity | Value | LCSC Part #
C1, C10, C11, C12, C13, C14, C15, C16, C17, C18, C19, C20, C21, C22, C23, C24, C25, C26, C27, C28, C29, C30, C31, C32, C33, C34, C35, C36, C37, C38, C39, C40, C41, C42, C43, C44, C45, C46, C47, C48, C51, C52, C53, C54, C55, C56, C57, C58, C59, C8, C9 | 0603 | 51 | 47nF
C2, C3, C4 | 0805 | 3 | 330nF
C49, C50 | 1206 | 2 | 22uF
C5 | 0603 | 1 | 22pF
C6 | 0603 | 1 | 47pF
C7 | 0603 | 1 | 100nF
D4 | D_PowerDI-123 | 1 | SBR3U60P1
F1 | 0603 | 1 | 32V 2A 0603
GND_10, GND_9, GND_8, GND_7, GND_6, GND_5, GND_4, GND_3, GND_2, GND | PinSocket_1x01_P2.54mm_Vertical | 10 | TestPoint
J1 | DIP-16_W7.62mm_Socket | 1 | Keyboard Connector
J10 | 694106301002_1 | 1 | 694106301002
J2, J4, J5 | L717SDE09PA4CH3F | 3 | DE9_Plug_MountingHoles
J3 | 1560099E | 1 | 156-0099-E
J6 | PinSocket_1x14_P2.54mm_Vertical | 1 | GPI/O
J7 | PinSocket_1x10_P2.54mm_Vertical | 1 | Conn_01x10
J8 | PinSocket_2x12_P2.54mm_Vertical | 1 | I/0
J9 | PinSocket_2x20_P2.54mm_Vertical | 1 | Conn_02x20_Counter_Clockwise
JP1 | SolderJumper-3_P1.3mm_Open_RoundedPad1.0x1.5mm_NumberLabels | 1 | ASCII D7
JP10 | SolderJumper-3_P1.3mm_Bridged12_RoundedPad1.0x1.5mm_NumberLabels | 1 | SolderJumper_3_Bridged12
JP11 | SolderJumper-3_P1.3mm_Bridged12_RoundedPad1.0x1.5mm_NumberLabels | 1 | Rom Window Size
JP12 | SolderJumper-3_P1.3mm_Bridged12_RoundedPad1.0x1.5mm_NumberLabels | 1 | EEPROM Bank (Manual/Auto)
JP13 | PinSocket_1x03_P2.54mm_Vertical | 1 | EEPROM Bank Sel
JP14 | PinSocket_1x03_P2.54mm_Vertical | 1 | EEPROM Write Protect
JP2, JP3, JP4, JP5, JP6, JP7, JP8, JP9 | SolderJumper-2_P1.3mm_Open_RoundedPad1.0x1.5mm | 8 | SolderJumper_2_Open
Q4 | SOT-23_Handsoldering | 1 | MMBT3904
R1, R2, R3 | 0603 | 3 | 2.2K
R10 | 0603 | 1 | 150R
R11 | 0603 | 1 | 200R
R5, R7 | 0603 | 2 | 1.5k
R6 | 0603 | 1 | 1M
R8 | 0603 | 1 | 2K
R9 | 0603 | 1 | 10R
TP1, TP10, TP11, TP12, TP13, TP14, TP15, TP16, TP17, TP18, TP19, TP2, TP3, TP4, TP5, TP6, TP7, TP8, TP9 | TestPoint_Pad_D2.5mm | 19 | TestPoint
TP20 | TestPoint_Pad_D2.5mm | 1 | CA2
U1 | MQFP-44_10x10mm_P0.8mm | 1 | W65C02SxQ
U10, U11 | SOIC-24W_7.5x15.4mm_P1.27mm | 2 | 74HC154
U12 | SOIC-20W_7.5x12.8mm_P1.27mm | 1 | 74HC273
U13 | TO-220-3_Horizontal_TabDown | 1 | OKI-78SR-5
U14 | PLCC-28 | 1 | 82C54_PLCC
U15, U23 | SOIC-20W_7.5x12.8mm_P1.27mm | 2 | 74HC373
U16, U22, U30 | SOIC-14_3.9x8.7mm_P1.27mm | 3 | 74HC32
U17 | TQFP-48_7x7mm_P0.5mm | 1 | TL16C550D/DL PT/PFB
U18 | TSSOP-28_4.4x9.7mm_P0.65mm | 1 | TRSF3243
U19 | SOIC-14_3.9x8.7mm_P1.27mm | 1 | 74HC86
U2 | SOIC-28W_7.5x17.9mm_P1.27mm | 1 | AT28HC64BF
U20 | PLCC-44 | 1 | W65C21SxPL
U21, U7 | SOIC-14_3.9x8.7mm_P1.27mm | 2 | 74HC02
U24 | DIP-40_W15.24mm | 1 | 6545
U25 | SOIC-28W_7.5x18.7mm_P1.27mm | 1 | AS6C6264
U26, U27, U28, U33, U39, U40, U41, U47, U48 | SOIC-16_3.9x9.9mm_P1.27mm | 9 | 74HC157
U29, U31, U49, U8, U9 | SOIC-14_3.9x8.7mm_P1.27mm | 5 | 74HC08
U3, U34 | SOIC-28W_7.5x17.9mm_P1.27mm | 2 | IS62C256AL
U32 | SOIC-14_3.9x8.7mm_P1.27mm | 1 | 74HC04
U35, U36, U42, U43 | SOIC-20W_7.5x12.8mm_P1.27mm | 4 | 74HC244
U37 | SOIC-20W_7.5x12.8mm_P1.27mm | 1 | 74HC574
U38 | SOIC-16_3.9x9.9mm_P1.27mm | 1 | 74HC165
U4, U5, U6 | SOIC-14_3.9x8.7mm_P1.27mm | 3 | 74HC00
U44 | SOIC-16_3.9x9.9mm_P1.27mm | 1 | 74HC163
U45 | SOIC-16_3.9x9.9mm_P1.27mm | 1 | 74HC174
U46 | SOIC-14_3.9x8.7mm_P1.27mm | 1 | 74HC74
X1 | Oscillator_SMD_Fordahl_DFAS11-4Pin_7.0x5.0mm | 1 | DFA-S11
X2 | Oscillator_SMD_Abracon_ASV-4Pin_7.0x5.1mm_HandSoldering | 1 | ASV-2.5MHz
Y1 | Crystal_HC49-U_Horizontal_1EP_style2 | 1 | 1.8432MHz

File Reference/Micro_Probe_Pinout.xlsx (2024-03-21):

Probe Pin | EXP Pin | Signal | Notes/Connector Name
Probe 1 |  |  | Address
D0 | 2 | A0
D1 | 3 | A1
D2 | 4 | A2
D3 | 5 | A3
D4 | 6 | A4
D5 | 7 | A5
D6 | 8 | A6
D7 | 9 | A7
D8 | 10 | A8
D9 | 11 | A9
D10 | 12 | A10
D11 | 13 | A11
D12 | 14 | A12
D13 | 15 | A13
D14 | 16 | A14
D15 | 17 | A5
CLK | 24 | CLK
Probe 2 |  |  | Data/Control
D0 | 39 | D0
D1 | 38 | D1
D2 | 37 | D2
D3 | 36 | D3
D4 | 35 | D4
D5 | 34 | D5
D6 | 33 | D6
D7 | 32 | D7
D8 | 31 | /IRQ | External Only (not What CPU sees)
D9 | 30 | /EXTSEL
D10 | 29 | /RST
D11 | 28 | SDA | 3.3V
D12 | 27 | SCL | 3.3V
D13 | 26 | /NMI | Open Drain
D14 | 19 | /WE
D15 | 18 | /RD
CLK | 25 | CPU_CLK_OUT
Probe 3 |  |  | Banksel/Misc
D0 | BS1 | BS3
D1 | BS2 | VBS0
D2 | BS3 | BS2
D3 | BS4 | VBS1
D4 | BS5 | BS1
D5 | BS6 | CHBS
D6 | BS7 | /V/CHRAM
D7 | BS8 | BS0
D8 | M1 | TP3
D9 | M2 | TP4
D10 | M3 | TP5
D11 | M4 | TP6
D12 | M5 | TP7
D13 | M6 | TP8
D14 | M7 | TP9
D15 | M8 | TP10
CLK | CLK2(23) | CLK2

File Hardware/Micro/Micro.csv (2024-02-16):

Reference | Value | Footprint | Datasheet | Sim.Device | Sim.Pins | Qty
C1-C4 | C | Capacitor_SMD:C_0603_1608Metric_Pad1.08x0.95mm_HandSolder | ~ |  |  | 4
C5 | 22pF | Capacitor_SMD:C_0603_1608Metric_Pad1.08x0.95mm_HandSolder | ~ |  |  | 1
C6 | 47pF | Capacitor_SMD:C_0603_1608Metric_Pad1.08x0.95mm_HandSolder | ~ |  |  | 1
C7 | 100nF | Capacitor_SMD:C_0603_1608Metric_Pad1.08x0.95mm_HandSolder | ~ |  |  | 1
D1-D3 | 1N4148W | Diode_SMD:D_SOD-123 | https://www.vishay.com/docs/85748/1n4148w.pdf | D | 1=K 2=A | 3
J1 | Keyboard Connector | Package_DIP:DIP-16_W7.62mm_Socket | ~ |  |  | 1
J2, J4, J5 | DE9_Plug_MountingHoles | SamacSys_Parts:L717SDE09PA4CH3F | ~ |  |  | 3
J3 | Conn_Coaxial |  | ~ |  |  | 1
J6 | GPI/O | Connector_PinSocket_2.54mm:PinSocket_1x14_P2.54mm_Vertical | ~ |  |  | 1
J7 | Conn_01x08 | Connector_PinSocket_2.54mm:PinSocket_1x08_P2.54mm_Vertical | ~ |  |  | 1
J8 | Conn_01x10 | Connector_PinSocket_2.54mm:PinSocket_1x10_P2.54mm_Vertical | ~ |  |  | 1
JP1 | ASCII D7 | Package_DIP:DIP-16_W7.62mm_Socket | ~ |  |  | 1
JP2-JP9 | SolderJumper_2_Open | Jumper:SolderJumper-2_P1.3mm_Open_RoundedPad1.0x1.5mm | ~ |  |  | 8
Q4 | MMBT3904 | Package_TO_SOT_SMD:SOT-23_Handsoldering | ~ |  |  | 1
R1-R3 | 2.2K | Resistor_SMD:R_0603_1608Metric_Pad0.98x0.95mm_HandSolder | ~ |  |  | 3
R4 | 4.7k | Resistor_SMD:R_0603_1608Metric_Pad0.98x0.95mm_HandSolder | ~ |  |  | 1
R5 | 1.5k | Resistor_SMD:R_0603_1608Metric_Pad0.98x0.95mm_HandSolder | ~ |  |  | 1
R6 | 1M | Resistor_SMD:R_0603_1608Metric_Pad0.98x0.95mm_HandSolder | ~ |  |  | 1
R7 | 1.5K | Resistor_SMD:R_0603_1608Metric_Pad0.98x0.95mm_HandSolder | ~ |  |  | 1
R8 | 2K | Resistor_SMD:R_0603_1608Metric_Pad0.98x0.95mm_HandSolder | ~ |  |  | 1
R9 | 10R | Resistor_SMD:R_0603_1608Metric_Pad0.98x0.95mm_HandSolder | ~ |  |  | 1
R10 | 150R | Resistor_SMD:R_0603_1608Metric_Pad0.98x0.95mm_HandSolder | ~ |  |  | 1
R11 | 200R | Resistor_SMD:R_0603_1608Metric_Pad0.98x0.95mm_HandSolder | ~ |  |  | 1
SW1 | -- mixed values -- |  |  |  |  | 1
U1 | W65C02SxQ | Package_QFP:MQFP-44_10x10mm_P0.8mm | http://www.westerndesigncenter.com/wdc/documentation/w65c02s.pdf |  |  | 1
U2 | AT28HC64BF | Package_SO:SOIC-28W_7.5x17.9mm_P1.27mm | https://www.mouser.com/datasheet/2/268/doc3648-1115086.pdf |  |  | 1
U3, U34 | IS62C256AL | Package_SO:SOIC-28W_7.5x17.9mm_P1.27mm | https://www.mouser.com/datasheet/2/198/62-65C256AL-258444.pdf |  |  | 2
U4-U6 | 74HC00 | Package_SO:SOIC-14_3.9x8.7mm_P1.27mm | http://www.ti.com/lit/gpn/sn74hct00 |  |  | 3
U7, U13, U21 | 74HC02 | Package_SO:SOIC-14_3.9x8.7mm_P1.27mm | -- mixed values -- |  |  | 3
U8, U9, U29, U31, U49 | 74HC08 | Package_SO:SOIC-14_3.9x8.7mm_P1.27mm | http://www.ti.com/lit/gpn/sn74LS08 |  |  | 5
U10, U11 | 74HC154 | Package_SO:SOIC-24W_7.5x15.4mm_P1.27mm | http://www.ti.com/lit/gpn/sn74LS154 |  |  | 2
U12, U15, U23 | 74HC373 | Package_SO:SOIC-20W_7.5x12.8mm_P1.27mm | -- mixed values -- |  |  | 3
U14 | 82C54_PLCC | Package_LCC:PLCC-28 | http://download.intel.com/design/archives/periphrl/docs/23124406.pdf |  |  | 1
U16, U22, U30 | 74HC32 | Package_SO:SOIC-14_3.9x8.7mm_P1.27mm | http://www.ti.com/lit/gpn/sn74LS32 |  |  | 3
U17 | TL16C550D/DL PT/PFB | Package_QFP:TQFP-48_7x7mm_P0.5mm | https://www.ti.com/general/docs/suppproductinfo.tsp?distId=26&gotoUrl=https://www.ti.com/lit/gpn/tl16c550d |  |  | 1
U18 | TRSF3243 | Package_SO:TSSOP-28_4.4x9.7mm_P0.65mm | https://www.ti.com/lit/gpn/trsf3243 |  |  | 1
U19 | 74HC86 | Package_SO:SOIC-14_3.9x8.7mm_P1.27mm | 74xx/74ls86.pdf |  |  | 1
U20 | W65C21SxPL | Package_LCC:PLCC-44 | http://www.westerndesigncenter.com/wdc/documentation/w65c21.pdf |  |  | 1
U24 | 6545 | Package_DIP:DIP-40_W15.24mm | http://www.6502.org/documents/datasheets/mos/mos_6545-1_crtc.pdf |  |  | 1
U25 | AS6C6264 | Package_SO:SOIC-28W_7.5x18.7mm_P1.27mm |  |  |  | 1
U26-U28, U39-U41, U47, U48 | 74HC157 | Package_SO:SOIC-16_3.9x9.9mm_P1.27mm | http://www.ti.com/lit/gpn/sn74LS157 |  |  | 8
U32 | 74HC04 | Package_SO:SOIC-14_3.9x8.7mm_P1.27mm | http://www.ti.com/lit/gpn/sn74LS04 |  |  | 1
U35, U36, U42, U43 | 74HC244 | Package_SO:SOIC-20W_7.5x12.8mm_P1.27mm | https://assets.nexperia.com/documents/data-sheet/74HC_HCT244.pdf |  |  | 4
U37 | 74HC574 | Package_SO:SOIC-20W_7.5x12.8mm_P1.27mm | http://www.ti.com/lit/gpn/sn74HCT574 |  |  | 1
U38 | 74HC165 | Package_SO:SOIC-16_3.9x9.9mm_P1.27mm | https://assets.nexperia.com/documents/data-sheet/74HC_HCT165.pdf |  |  | 1
U44 | 74HC163 | Package_SO:SOIC-16_3.9x9.9mm_P1.27mm | http://www.ti.com/lit/gpn/sn74LS163 |  |  | 1
U45 | 74HC174 | Package_SO:SOIC-16_3.9x9.9mm_P1.27mm | http://www.ti.com/lit/gpn/sn74LS174 |  |  | 1
U46 | 74HC74 | Package_SO:SOIC-14_3.9x8.7mm_P1.27mm | 74xx/74hc_hct74.pdf |  |  | 1
X1 | DFA-S11 | Oscillator:Oscillator_SMD_Fordahl_DFAS11-4Pin_7.0x5.0mm | http://www.metatech.com.hk/product/fordahl/pdf/2002%20TCXO%20Page%2043-58.pdf |  |  | 1
X2 | ASV-2.5MHz | Oscillator:Oscillator_SMD_Abracon_ASV-4Pin_7.0x5.1mm_HandSoldering | http://www.abracon.com/Oscillators/ASV.pdf |  |  | 1
Y1 | 1.8432MHz |  | ~ |  |  | 1

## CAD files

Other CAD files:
Software/3rd Party Software/CO2-Pocket-SBC-2.5-main/Software/DOS65/Core OS/DOS65-MAIN-V320.obj
Software/3rd Party Software/CO2-Pocket-SBC-2.5-main/Software/DOS65/Utilities/V3 Utils/Assembler/ASM304.obj
Software/3rd Party Software/CO2-Pocket-SBC-2.5-main/Software/DOS65/Utilities/V3 Utils/MakeCOM/MKCOM202.obj
Software/3rd Party Software/CO2-Pocket-SBC-2.5-main/Software/DOS65/Utilities/V3 Utils/Submit/SUB300.obj
Software/3rd Party Software/CO2-Pocket-SBC-2.5-main/Software/DOS65/Utilities/V3 Utils/Super Directory/SD103.obj
Software/3rd Party Software/CO2-Pocket-SBC-2.5-main/Software/DOS65/Utilities/V3 Utils/Xmodem/XSBC123.obj
Software/3rd Party Software/CO2-Pocket-SBC-2.5-main/Software/ROM Code/BIOS/C02BIOS4.obj
Software/3rd Party Software/CO2-Pocket-SBC-2.5-main/Software/ROM Code/Monitor/C02Monitor4.obj
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

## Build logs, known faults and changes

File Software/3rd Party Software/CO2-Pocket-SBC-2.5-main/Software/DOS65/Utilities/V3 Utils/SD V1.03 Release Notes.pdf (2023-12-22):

SUPER DIRECTORY (SD) V1.03 RELEASE NOTES

Super Directory (SD) v1.03 is the fourth release of a directory utility that makes organizing and using our electronic mass storage devices simpler and faster. It was derived from SD V4.12 for CP/M.

Assembly –the supplied source code is configured for the WDC 2014 tool set for the 65C02 operating in a Windows environment. Use under a different tool set will require code changes. No 65C02 instructions or unique features were used.

Configuring – Before assembling the utility set the “V3” conditional statement to reflect use in either a DOS/65 V2.1 or a V3.0 environment. V2.1 can only handle a user area of zero while V3 can handle user areas of 0 through 15. There are other conditional assembly options that can be changed.

Running – run SD and use it just as you would use DIR. The following are all valid SD command lines:

“SD C:”

“SD new*.com”

Options – In the space immediately following the file definition, options may be entered as follows:

1. First ensure that a valid file definition (UFN or AFN) immediately
follows the SD and before any attempt to enter options. This is
because the option string can look like a file definition.
2. An option string must be started with a “=”, e.g., “SD *.* =”
3. Enter one or both of the following option commands:
a. “a” to show directory results for all user areas, e. g., “SD C:*.* =a”
b. “n” to cancel the screen full pause. This is especially useful if you use ctrl-P to echo the console stream to your printer to get a printed directory listing.
4. You can also enter an option string using a “u” to direct a listing of a specific user area, e. g., “SD C:*.* =u5” that will create a directory listing of drive C but only of user area 5.

Speed - SD is fast but can be improved. There is a noticeable pause as it starts processing a new user area. Some of that pause is the Shell sort but that is already optimized except possibly for implementing a two-layer file structure so
COMPARE and especially SWAP subroutines mostly just handle an array of word length pointers. I will start on that improvement right away.

Revision History

V1.00 – initial release.

V1.01 – fixes bug in V1.00 that caused incorrect display of files having the character “$” anywhere in the file name or extension.

V1.02 - significant improvement in speed achieved by eliminating redundant directory searches. In one typical run of SD against all user areas of an 8 MB CF drive total execution time was reduced from 106 seconds to 83 seconds – a 22% improvement.

V1.03 – changed option character to “=”.

Bug Reports – please report any problems found to me at richardaleary@gmail.com.

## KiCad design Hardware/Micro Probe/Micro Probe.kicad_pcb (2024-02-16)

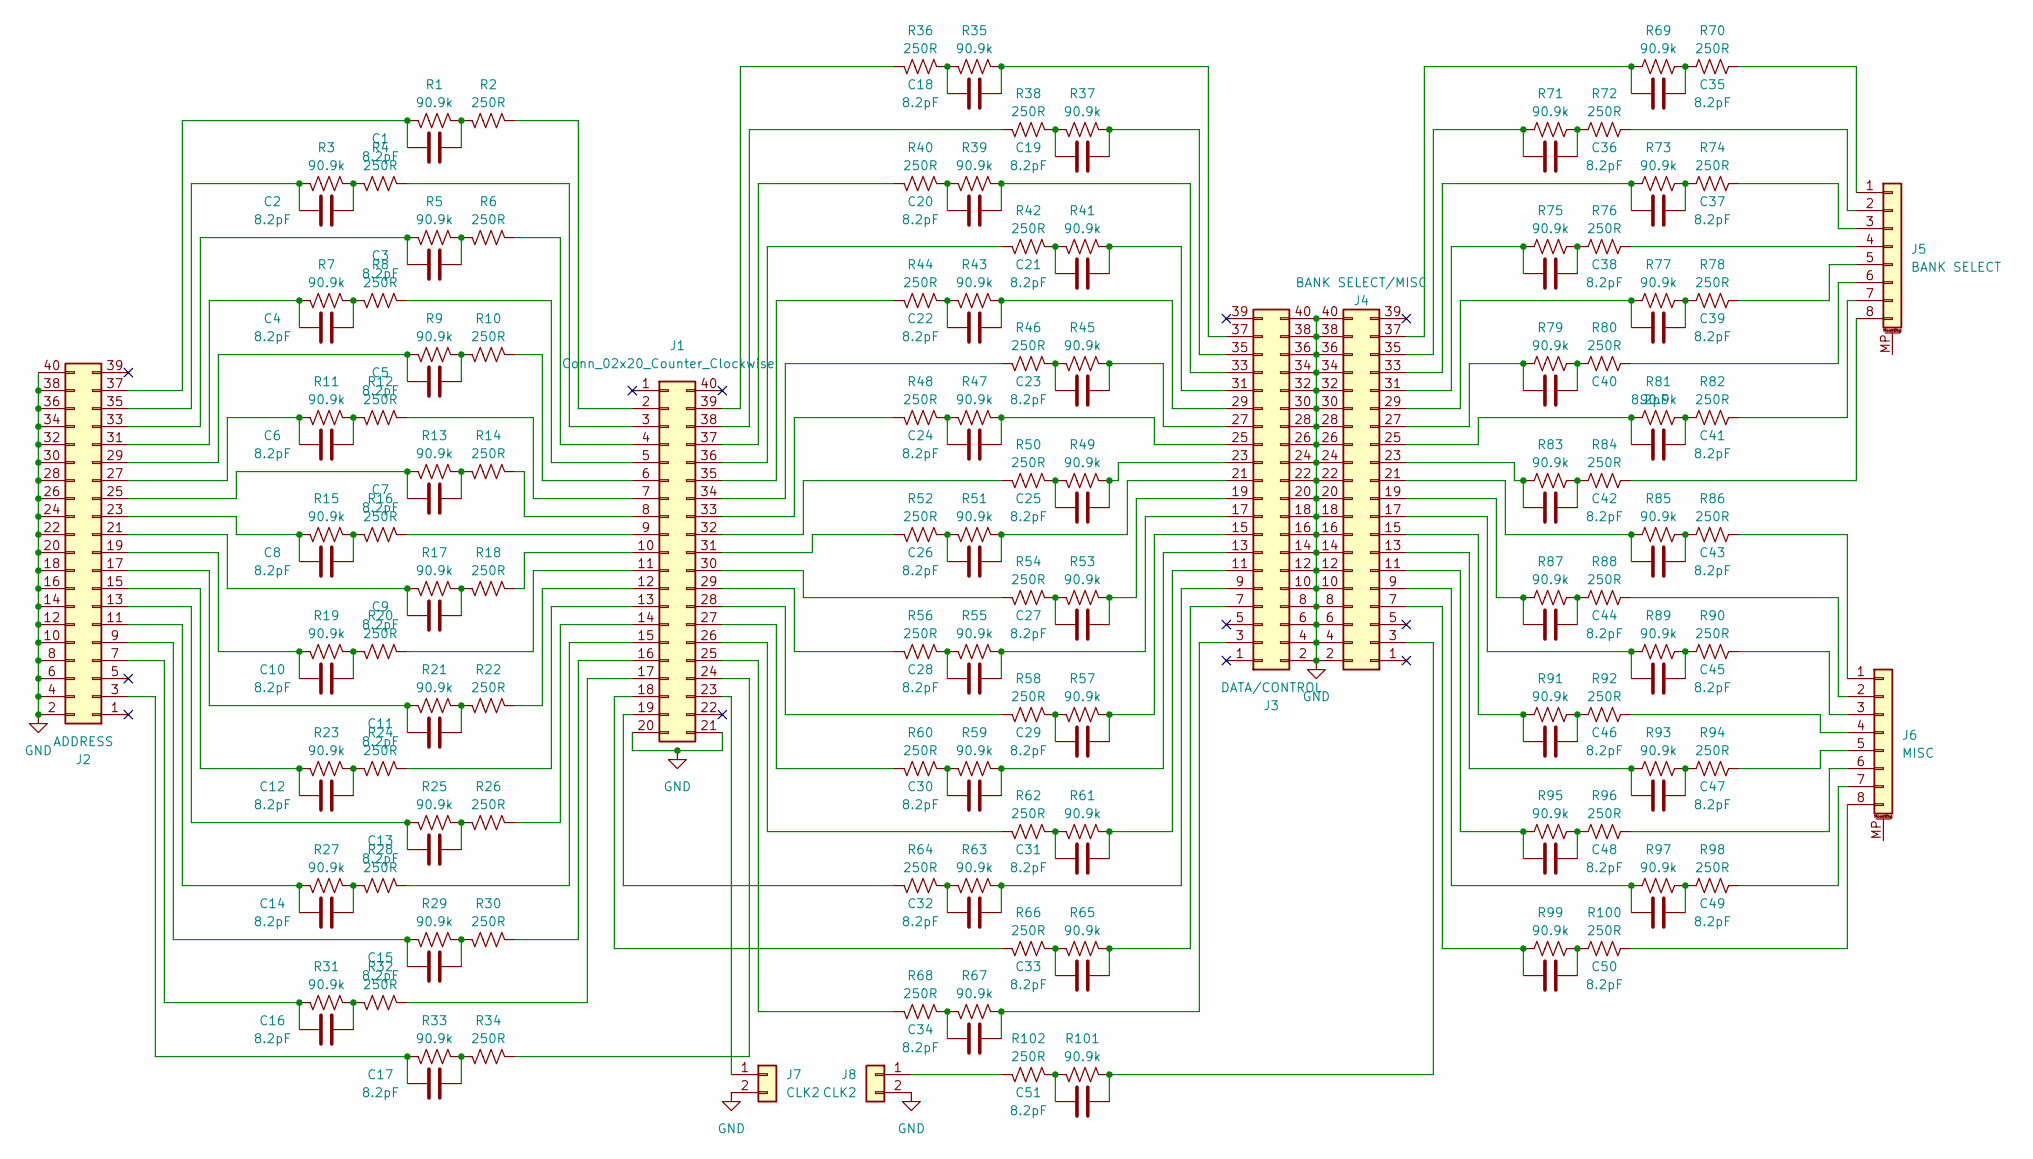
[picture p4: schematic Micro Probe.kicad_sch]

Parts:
C1, C2, C3, C4, C5, C6, C7, C8, C9, C10, C11, C12, C13, C14, C15, C16, C17, C18, C19, C20, C21, C22, C23, C24, C25, C26, C27, C28, C29, C30, C31, C32, C33, C34, C35, C36, C37, C38, C39, C40, C41, C42, C43, C44, C45, C46, C47, C48, C49, C50, C51: 8.2pF; R_0603_1608Metric
J1: Conn_02x20_Counter_Clockwise; PinHeader_2x20_P2.54mm_Vertical
J2: ADDRESS; PinHeader_2x20_P2.54mm_Vertical
J3: DATA/CONTROL; PinHeader_2x20_P2.54mm_Vertical
J4: BANK SELECT/MISC; PinHeader_2x20_P2.54mm_Vertical
J5: BANK SELECT; JST_SH_SM08B-SRSS-TB_1x08-1MP_P1.00mm_Horizontal
J6: MISC; JST_SH_SM08B-SRSS-TB_1x08-1MP_P1.00mm_Horizontal
J7, J8: CLK2; JST_SH_BM02B-SRSS-TB_1x02-1MP_P1.00mm_Vertical
R1, R3, R5, R7, R9, R11, R13, R15, R17, R19, R21, R23, R25, R27, R29, R31, R33, R35, R37, R39, R41, R43, R45, R47, R49, R51, R53, R55, R57, R59, R61, R63, R65, R67, R69, R71, R73, R75, R77, R79, R81, R83, R85, R87, R89, R91, R93, R95, R97, R99, R101: 90.9k; R_0603_1608Metric
R2, R4, R6, R8, R10, R12, R14, R16, R18, R20, R22, R24, R26, R28, R30, R32, R34, R36, R38, R40, R42, R44, R46, R48, R50, R52, R54, R56, R58, R60, R62, R64, R66, R68, R70, R72, R74, R76, R78, R80, R82, R84, R86, R88, R90, R92, R94, R96, R98, R100, R102: 250R; R_0603_1608Metric

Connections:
GND: J1.20, J1.21, J2.2, J2.4, J2.6, J2.8, J2.10, J2.12, J2.14, J2.16, J2.18, J2.20, J2.22, J2.24, J2.26, J2.28, J2.30, J2.32, J2.34, J2.36, J2.38, J2.40, J3.2, J3.4, J3.6, J3.8, J3.10, J3.12, J3.14, J3.16, J3.18, J3.20, J3.22, J3.24, J3.26, J3.28, J3.30, J3.32, J3.34, J3.36, J3.38, J3.40, J4.2, J4.4, J4.6, J4.8, J4.10, J4.12, J4.14, J4.16, J4.18, J4.20, J4.22, J4.24, J4.26, J4.28, J4.30, J4.32, J4.34, J4.36, J4.38, J4.40, J7.2, J8.2
unnamed: C1.1, R1.1, R2.2
unnamed: C2.1, R3.1, R4.2
unnamed: C3.1, R5.1, R6.2
unnamed: C4.1, R7.1, R8.2
unnamed: C5.1, R9.1, R10.2
unnamed: C6.1, R11.1, R12.2
unnamed: C7.1, R13.1, R14.2
unnamed: C8.1, R15.1, R16.2
unnamed: C9.1, R17.1, R18.2
unnamed: C10.1, R19.1, R20.2
unnamed: C11.1, R21.1, R22.2
unnamed: C12.1, R23.1, R24.2
unnamed: C13.1, R25.1, R26.2
unnamed: C14.1, R27.1, R28.2
unnamed: C15.1, R29.1, R30.2
unnamed: C16.1, R31.1, R32.2
unnamed: C17.1, R33.1, R34.2
unnamed: C18.2, R35.2, R36.1
unnamed: C19.2, R37.2, R38.1
unnamed: C20.2, R39.2, R40.1
unnamed: C21.2, R41.2, R42.1
unnamed: C22.2, R43.2, R44.1
unnamed: C23.2, R45.2, R46.1
unnamed: C24.2, R47.2, R48.1
unnamed: C25.2, R49.2, R50.1
unnamed: C26.2, R51.2, R52.1
unnamed: C27.2, R53.2, R54.1
unnamed: C28.2, R55.2, R56.1
unnamed: C29.2, R57.2, R58.1
unnamed: C30.2, R59.2, R60.1
unnamed: C31.2, R61.2, R62.1
unnamed: C32.2, R63.2, R64.1
unnamed: C33.2, R65.2, R66.1
unnamed: C34.2, R67.2, R68.1
unnamed: C35.2, R69.2, R70.1
unnamed: C36.2, R71.2, R72.1
unnamed: C37.2, R73.2, R74.1
unnamed: C38.2, R75.2, R76.1
unnamed: C39.2, R77.2, R78.1
unnamed: C40.2, R79.2, R80.1
unnamed: C41.2, R81.2, R82.1
unnamed: C42.2, R83.2, R84.1
unnamed: C43.2, R85.2, R86.1
unnamed: C44.2, R87.2, R88.1
unnamed: C45.2, R89.2, R90.1
unnamed: C46.2, R91.2, R92.1
unnamed: C47.2, R93.2, R94.1
unnamed: C48.2, R95.2, R96.1
unnamed: C49.2, R97.2, R98.1
unnamed: C50.2, R99.2, R100.1
unnamed: C51.2, R101.2, R102.1
unnamed: J1.2, R2.1
unnamed: J1.3, R4.1
unnamed: J1.4, R6.1
unnamed: J1.5, R8.1
unnamed: J1.6, R10.1
unnamed: J1.7, R12.1
unnamed: J1.8, R14.1
unnamed: J1.9, R16.1
unnamed: J1.10, R18.1
unnamed: J1.11, R20.1
unnamed: J1.12, R22.1
unnamed: J1.13, R24.1
unnamed: J1.14, R26.1
unnamed: J1.15, R28.1
unnamed: J1.16, R30.1
unnamed: J1.17, R32.1
unnamed: J1.18, R66.2
unnamed: J1.19, R64.2
unnamed: J1.23, J7.1, J8.1, R102.2
unnamed: J1.24, R34.1
unnamed: J1.25, R68.2
unnamed: J1.26, R62.2
unnamed: J1.27, R60.2
unnamed: J1.28, R58.2
unnamed: J1.29, R56.2
unnamed: J1.30, R54.2
unnamed: J1.31, R52.2
unnamed: J1.32, R50.2
unnamed: J1.33, R48.2
unnamed: J1.34, R46.2
unnamed: J1.35, R44.2
unnamed: J1.36, R42.2
unnamed: J1.37, R40.2
unnamed: J1.38, R38.2
unnamed: J1.39, R36.2
unnamed: C17.2, J2.3, R33.2
unnamed: C16.2, J2.7, R31.2
unnamed: C15.2, J2.9, R29.2
unnamed: C14.2, J2.11, R27.2
unnamed: C13.2, J2.13, R25.2
unnamed: C12.2, J2.15, R23.2
unnamed: C11.2, J2.17, R21.2
unnamed: C10.2, J2.19, R19.2
unnamed: C9.2, J2.21, R17.2
unnamed: C8.2, J2.23, R15.2
unnamed: C7.2, J2.25, R13.2
unnamed: C6.2, J2.27, R11.2
unnamed: C5.2, J2.29, R9.2
unnamed: C4.2, J2.31, R7.2
unnamed: C3.2, J2.33, R5.2
unnamed: C2.2, J2.35, R3.2
unnamed: C1.2, J2.37, R1.2
unnamed: C34.1, J3.3, R67.1
unnamed: C33.1, J3.7, R65.1
unnamed: C32.1, J3.9, R63.1
unnamed: C31.1, J3.11, R61.1
unnamed: C30.1, J3.13, R59.1
unnamed: C29.1, J3.15, R57.1
unnamed: C28.1, J3.17, R55.1
unnamed: C27.1, J3.19, R53.1
unnamed: C26.1, J3.21, R51.1
unnamed: C25.1, J3.23, R49.1
unnamed: C24.1, J3.25, R47.1
unnamed: C23.1, J3.27, R45.1
unnamed: C22.1, J3.29, R43.1
unnamed: C21.1, J3.31, R41.1
unnamed: C20.1, J3.33, R39.1
unnamed: C19.1, J3.35, R37.1
unnamed: C18.1, J3.37, R35.1
unnamed: C51.1, J4.3, R101.1
unnamed: C50.1, J4.7, R99.1
unnamed: C49.1, J4.9, R97.1
unnamed: C48.1, J4.11, R95.1
unnamed: C47.1, J4.13, R93.1
unnamed: C46.1, J4.15, R91.1
unnamed: C45.1, J4.17, R89.1
unnamed: C44.1, J4.19, R87.1
unnamed: C43.1, J4.21, R85.1
unnamed: C42.1, J4.23, R83.1
unnamed: C41.1, J4.25, R81.1
unnamed: C40.1, J4.27, R79.1
unnamed: C39.1, J4.29, R77.1
unnamed: C38.1, J4.31, R75.1
unnamed: C37.1, J4.33, R73.1
unnamed: C36.1, J4.35, R71.1
unnamed: C35.1, J4.37, R69.1
unnamed: J5.1, R70.2
unnamed: J5.2, R72.2
unnamed: J5.3, R74.2
unnamed: J5.4, R76.2
unnamed: J5.5, R78.2
unnamed: J5.6, R80.2
unnamed: J5.7, R82.2
unnamed: J5.8, R84.2
unnamed: J6.1, R86.2
unnamed: J6.2, R88.2
unnamed: J6.3, R90.2
unnamed: J6.4, R92.2
unnamed: J6.5, R94.2
unnamed: J6.6, R96.2
unnamed: J6.7, R98.2
unnamed: J6.8, R100.2

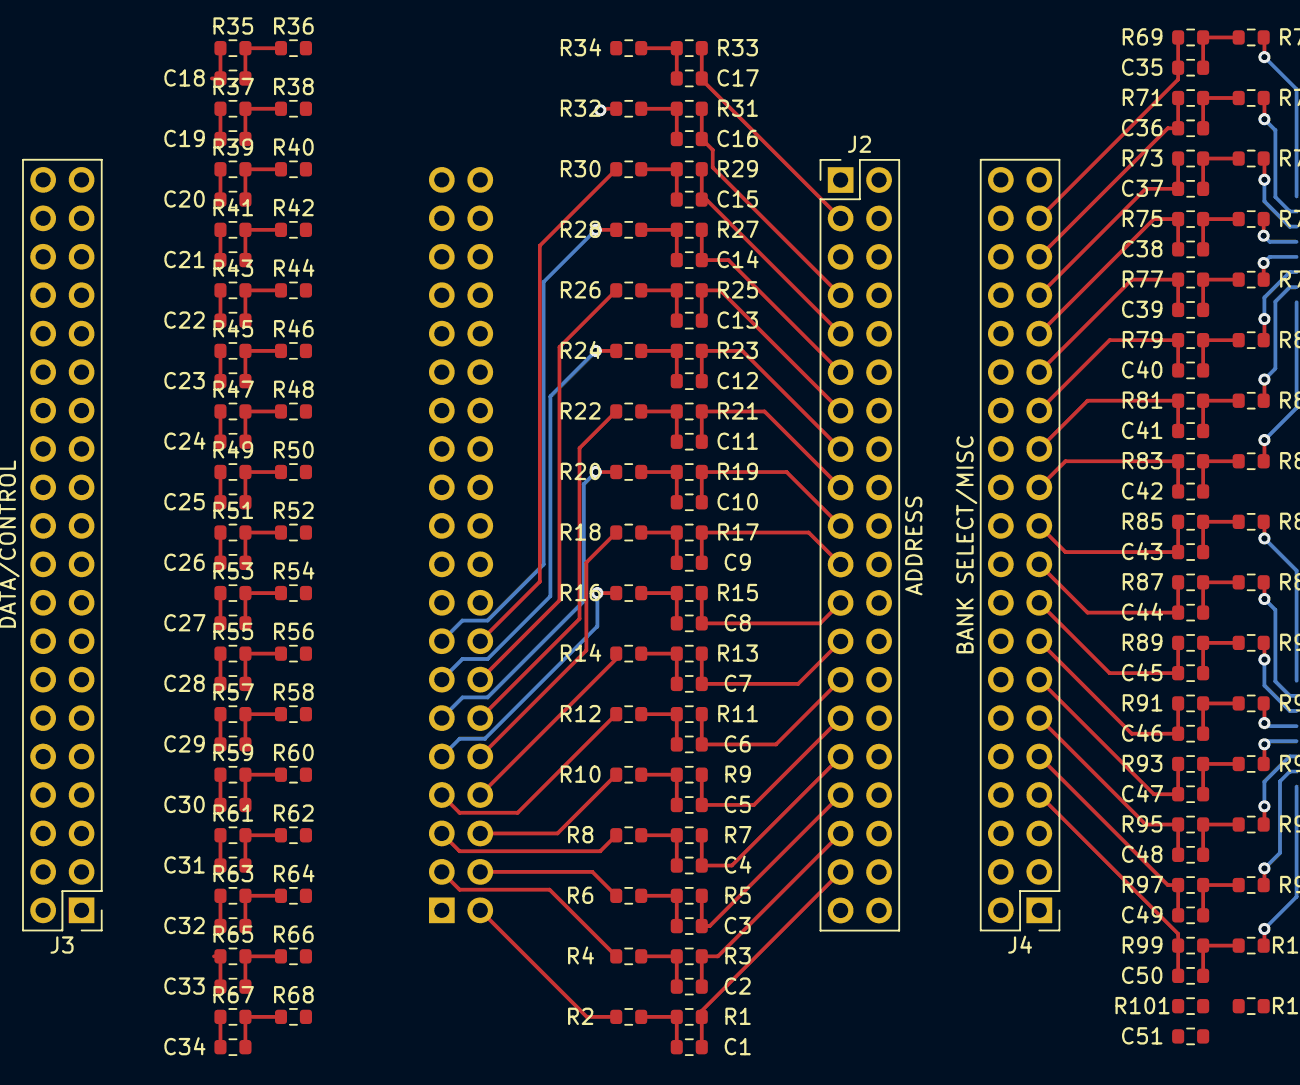
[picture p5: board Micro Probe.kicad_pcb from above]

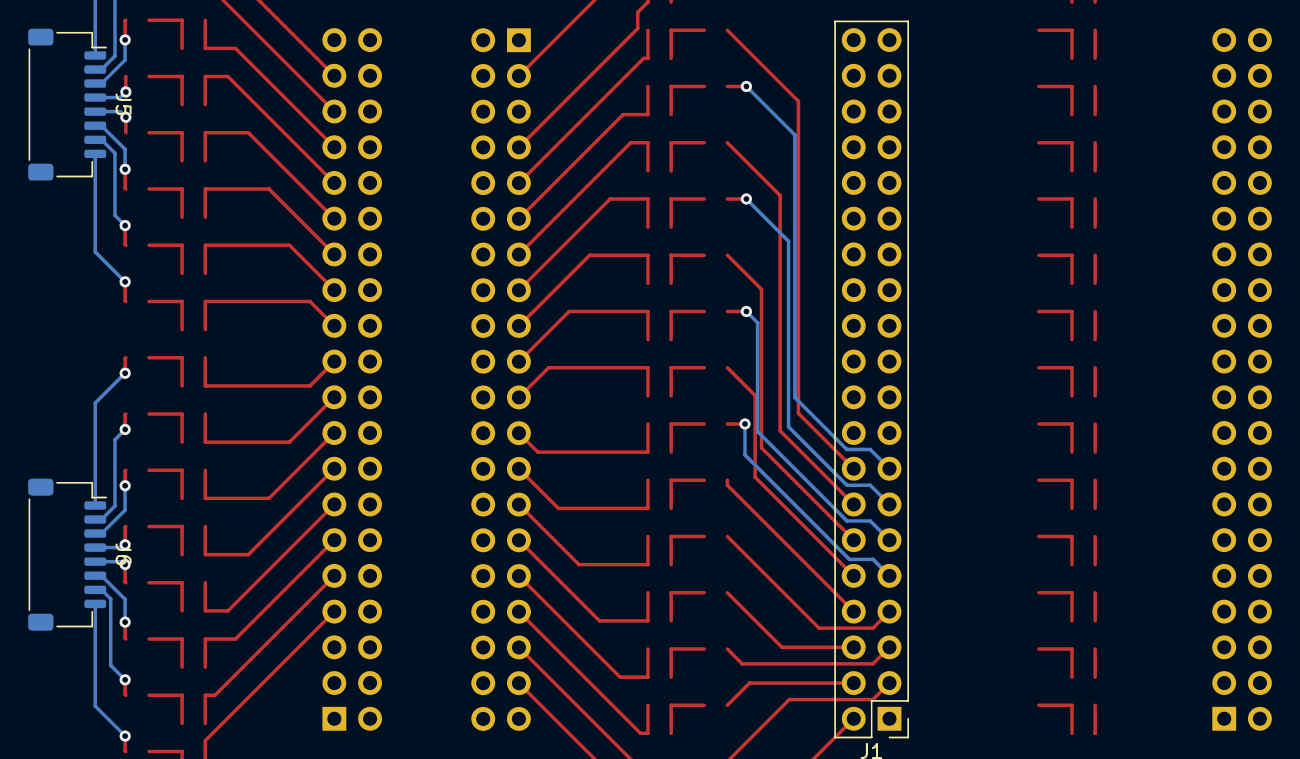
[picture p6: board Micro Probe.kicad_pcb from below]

Board: 2 copper layers, 159 parts (3 on the bottom side), 154 nets.

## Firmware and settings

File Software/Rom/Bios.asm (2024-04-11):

;************************************************************************************
;*																					*
;*								VMC Bios for Rev 1									*
;*																					*
;*		By Jake Donovan			started on 1/3/2024									*
;*																					*
;************************************************************************************





; features
;
; --------hardware---------
;





























;************************************
;*				Main  				*
;************************************
Entrypoint_Warm:
	JMP Mon
Entrypoint:	
	SEI
	LDA #$C1		;Clock gen id read
	LDX #03
	JSR B_I2C
	ROR
	ROR
	BCC Entrypoint_Warm
Entrypoint_Cold:
	LDX #$FF
	TXS				;Init Stack Pointer
	STX R_PIA_GPIO		;Init Gpio to output POSTCODE
	LDA #%00000100
	STA R_PIA_GPIO_CTRL
	STA R_BANK_SEL	;Conviniently dont have to load a different value
	INC R_PIA_GPIO		;DEBUG 01
Entrypoint_Cold_Serial_Setup:	;sets serial to 9600 8 E 1
	LDA #%00001011	;DIV_LATCH enable, No tx break, no force parity, Even parity, Yes B_Parity, 1 stop bit, 8 bit word
	STA R_COMM_LINE_CTRL
	LDA #14
	JSR B_COMM_Set_Speed
	INC R_PIA_GPIO		;DEBUG 02
	LDA #%00000111
	STA R_COMM_FIFO_CTRL
	LDA #%00100010
	STA R_COMM_MODM_CTRL
	INC R_PIA_GPIO		;DEBUG 03
	LDX #$00
	LDY #$00
	LDA #$5A
Entrypoint_MEMTEST_ZP: ;tests zp with patterns $5A $A5 $FF $00, also indirectly clears memory by filling  w/ $00 last
@Loop_STA:
	STA $00, X
	INX
	BNE @Loop_STA	;done storing set value
@Loop_CMP:
	CMP $00, X
	BNE @Error
	INX
	BNE @Loop_CMP
	INY
	CMP #$04		
	BEQ Entrypoint_MEMTEST_ZP_Done
	LDA Entrypoint_MEMTEST_Values, Y
	BRA Entrypoint_MEMTEST_ZP
@Error:
			;will write later

Entrypoint_MEMTEST_ZP_Done:		;Prints RamCount and ZP_ok prompt
	INC R_PIA_GPIO		;Debug 04
	LDA #<Entrypoint_Memtest_Splash
	STA ZP_Pointer1_LSB
	LDA #>Entrypoint_Memtest_Splash
	STA ZP_Pointer1_MSB
	JSR B_COMM_TX_Str
	LDA #$00
	JSR	Entrypoint_MEMTEST_Print_B_Page
	LDX #01
	LDY #03
	JSR B_COMM_MoveCsr
	LDA #<Entrypoint_MEMTEST_Prompt_zp
	STA ZP_Pointer1_LSB
	LDA #>Entrypoint_MEMTEST_Prompt_zp
	STA ZP_Pointer1_MSB
	JSR B_COMM_TX_Str
	INC R_PIA_GPIO		;Debug 05
	LDA #%00000100				;Set ram bank to 1 for ram test
	STA ZP_INT_BSR_MIRROR
	STA R_BANK_SEL
	LDA $01
	STA ZP_Pointer1_MSB
	STZ ZP_Pointer1_LSB
	LDA #$5A
	LDY #$00
	LDX #$00
Entrypoint_MEMTEST:
@Loop_STA:
	STA (ZP_Pointer1_LSB)		
	INC ZP_Pointer1_LSB
	BNE @Loop_STA
@Loop_CMP:
	CMP (ZP_Pointer1_LSB)
	BNE @Error
	INC ZP_Pointer1_LSB
	BNE @Loop_CMP
	INY
	CPY #$04
	BEQ @Entrypoint_MEMTEST_Next_B_Page
@Return:
	LDA Entrypoint_MEMTEST_Values, Y
	BRA Entrypoint_MEMTEST
	
	
@Entrypoint_MEMTEST_Next_B_Page:	;Add offset to RamCount if necisary
	LDA ZP_Pointer1_MSB
	BBR3 ZP_INT_BSR_MIRROR, @No_Add
	CLC
	BBS2 ZP_INT_BSR_MIRROR, @Add_40h
	ADC #$20
	.byte $2C
@Add_40h:
	ADC #$40
@No_Add:
	JSR Entrypoint_MEMTEST_Print_B_Page
	INC ZP_Pointer1_MSB	;check if 
	LDA #$40
	CMP ZP_Pointer1_MSB
	BNE @No_Bankswitch
	STA ZP_Pointer1_MSB
	LDA ZP_INT_BSR_MIRROR
	CLC 
	ADC #%00000100
	CMP #%00010000
	BEQ @Done
	STA ZP_INT_BSR_MIRROR
@No_Bankswitch:
	LDY #$00
	BRA @Return

@Error:
	LDA #$F0
	STA R_PIA_GPIO
	LDX ZP_Pointer1_LSB
	LDY ZP_Pointer1_LSB
	LDA #<Entrypoint_MEMTEST_Prompt_Badram
	STA ZP_Pointer1_LSB
	LDA #>Entrypoint_MEMTEST_Prompt_Badram
	STA ZP_Pointer1_MSB
	JSR B_COMM_TX_Str
	TXA
	JSR B_Data_Hex2ASC
	JSR B_COMM_TX_Char
	TXA 
	JSR B_COMM_TX_Char	
	TYA
	JSR B_Data_Hex2ASC
	JSR B_COMM_TX_Char
	TXA 
	JSR B_COMM_TX_Char
	STP
	
	
@Done:
	INC R_PIA_GPIO		;Debug 06
	LDA #<Entrypoint_MEMTEST_Prompt_ram
	STA ZP_Pointer1_LSB
	LDA #>Entrypoint_MEMTEST_Prompt_ram
	STA ZP_Pointer1_MSB
	LDX #01
	LDY #04
	JSR B_COMM_MoveCsr
	JSR B_COMM_TX_Str
	
Entrypoint_Test_CLK:
	
@Enable_Clk2:
	INC R_PIA_GPIO		;Debug 07
	LDA #$C0		;Clock gen id write
	LDX #03
	LDY #$02 		;Make sure CLK2 is disabled before checking which clock is used by timer
	JSR B_I2C
	LDA #$FF
	TAX
	JSR B_TIME_Delay
	LDA #%11100010	;Readback Status For Counter 0
	STA R_TIME_CTRL
	BIT R_TIME_0
	BVC @Using_CPU_CLK
	LDA #%00000001
	TSB ZP_Bios_Error	;using CLK2
@Using_CPU_CLK:
	LDA #%00110000			;Disable counting
	STA R_TIME_CTRL
	INC R_PIA_GPIO		;Debug 08	
	LDA #$C0		;Start CLK2
	LDX #03
	LDY #$00
	JSR B_I2C
@Check_Bad_Timer:	;if both reads return Null Count, Timer Bad
	LDA #$ff
	TAX
	JSR B_TIME_Delay
	LDA #%11100010	;Readback Status For Counter 0
	STA R_TIME_CTRL
	BIT R_TIME_0
	BVC @Timer_Ok
	LDA #<Entrypoint_Prompt_BadTimer
	STA ZP_Pointer1_LSB
	LDA #>Entrypoint_Prompt_BadTimer
	STA ZP_Pointer1_MSB
	JSR B_COMM_TX_Str
	STP
@Timer_Ok:
	LDA #%00110000
	STA R_TIME_CTRL
	INC R_PIA_GPIO		;Debug 09
	LDA #<Entrypoint_Prompt_Timer_OK
	STA ZP_Pointer1_LSB
	LDA #>Entrypoint_Prompt_Timer_OK
	STA ZP_Pointer1_MSB
	JSR B_COMM_TX_Str
	
Entrypoint_Done:
	JSR B_COMM_ClsScr
	LDA #<Entrypoint_Prompt_Done
	STA ZP_Pointer1_LSB
	LDA #>Entrypoint_Prompt_Done
	STA ZP_Pointer1_MSB
	JSR B_COMM_TX_Str
	JMP Mon
















Entrypoint_MEMTEST_Print_B_Page:
	PHA
	LDX #1
	LDY #2
	JSR B_COMM_MoveCsr
	LDA #$24		;$
	JSR B_COMM_TX_Char
	PLA
	JSR B_Data_Hex2ASC
	JSR B_COMM_TX_Char
	TXA
	JSR B_COMM_TX_Char
	LDA #$30
	JSR B_COMM_TX_Char
	RTS
	
	
Entrypoint_MEMTEST_Values:
.byte $5A, $A5, $FF, $00
Entrypoint_Memtest_Splash:
.asciiz "VMC RomBIOS 1.0\t2024 Jake Donovan\tTurn on local echo!"
Entrypoint_MEMTEST_Prompt_zp:
.asciiz	"ZP OK!"
Entrypoint_MEMTEST_Prompt_ram:
.asciiz "Ram OK!"
Entrypoint_MEMTEST_Prompt_Badram:
.asciiz "Bad Ram @$"
Entrypoint_Prompt_BadTimer:
.asciiz "Bad TIMER"
Entrypoint_Prompt_Timer_OK:
.asciiz "TIMER OK!"
Entrypoint_Prompt_Done:
.asciiz "System Ready"


; write control word to prevent out from going low


; ======Video=====
; 
; Set mode 
;				(initiallize screen to specific settings
; chram copy
;		 point to a location and copy into chram at a specific location in chram. 
;		header is optional, compression is optional (likely rle)
; smooth scroll
; 		vertical and horizontal. will need to be called once per frame
;		https://www.cpcwiki.eu/index.php/Programming:Hardware_scrolling_the_screen_using_the_CRTC
; vid bank swap CPU
;		switches what bank is visible to cpu. currently only vram, can be updated to include chram
; vid bank swap crtc
;		same as above, just for crtc
;

; ======Keyboard=======
; readkey
;		read currently pressed key, not irq
BI_ReadKey:
	PHX
	LDX ZP_Key_Buffer_Read_Pointer
	CPX ZP_Key_Buffer_Pointer
	CLC 
	BNE @OK
	PLX
	SEC
	RTS
@OK:
	LDA $0200, X
	INC ZP_Key_Buffer_Read_Pointer
	RTS
	
	



;
; ======timer=====
; Timer setup
;	 	enable, and start timer of certain length
BI_TIME_Delay: ; start delay with LSB of A and MSB of X cycles. returns 5 cycles into the count due to the RTS instruction. 
			;39 cycles  19.5us @2mhz  (+ 10 cycles to set up 5us @2mhz for a total of 24.5us)
	PHA   					;3
	LDA #%00110000			;2
	STA R_TIME_CTRL			;4
	LDA	ZP_INT_TIE_MIRROR	;3
	ORA #%00000001			;2
	STA ZP_INT_TIE_MIRROR	;3
	STA R_TIE				;4
	PLA						;4
	STA R_TIME_0			;4
	STX R_TIME_0			;4
	RTS						;6
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

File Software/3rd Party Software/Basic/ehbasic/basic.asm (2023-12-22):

; Enhanced BASIC to assemble under 6502 simulator, $ver 2.22

; $E7E1 $E7CF $E7C6 $E7D3 $E7D1 $E7D5 $E7CF $E81E $E825

; 2.00	new revision numbers start here
; 2.01	fixed LCASE$() and UCASE$()
; 2.02	new get value routine done
; 2.03	changed RND() to galoise method
; 2.04	fixed SPC()
; 2.05	new get value routine fixed
; 2.06	changed USR() code
; 2.07	fixed STR$()
; 2.08	changed INPUT and READ to remove need for $00 start to input buffer
; 2.09	fixed RND()
; 2.10	integrated missed changes from an earlier version
; 2.20	added ELSE to IF .. THEN and fixed IF .. GOTO <statement> to cause error
; 2.21	fixed IF .. THEN RETURN to not cause error
; 2.22	fixed RND() breaking the get byte routine

; zero page use ..

LAB_WARM 		= $00		; BASIC warm start entry point
Wrmjpl 		= LAB_WARM+1; BASIC warm start vector jump low byte
Wrmjph 		= LAB_WARM+2; BASIC warm start vector jump high byte

Usrjmp		= $0A		; USR function JMP address
Usrjpl		= Usrjmp+1	; USR function JMP vector low byte
Usrjph		= Usrjmp+2	; USR function JMP vector high byte
Nullct		= $0D		; nulls output after each line
TPos			= $0E		; BASIC terminal position byte
TWidth		= $0F		; BASIC terminal width byte
Iclim			= $10		; input column limit
Itempl		= $11		; temporary integer low byte
Itemph		= Itempl+1	; temporary integer high byte

nums_1		= Itempl	; number to bin/hex string convert MSB
nums_2		= nums_1+1	; number to bin/hex string convert
nums_3		= nums_1+2	; number to bin/hex string convert LSB

Srchc			= $5B		; search character
Temp3			= Srchc	; temp byte used in number routines
Scnquo		= $5C		; scan-between-quotes flag
Asrch			= Scnquo	; alt search character

XOAw_l		= Srchc	; eXclusive OR, OR and AND word low byte
XOAw_h		= Scnquo	; eXclusive OR, OR and AND word high byte

Ibptr			= $5D		; input buffer pointer
Dimcnt		= Ibptr	; # of dimensions
Tindx			= Ibptr	; token index

Defdim		= $5E		; default DIM flag
Dtypef		= $5F		; data type flag, $FF=string, $00=numeric
Oquote		= $60		; open quote flag (b7) (Flag: DATA scan; LIST quote; memory)
Gclctd		= $60		; garbage collected flag
Sufnxf		= $61		; subscript/FNX flag, 1xxx xxx = FN(0xxx xxx)
Imode			= $62		; input mode flag, $00=INPUT, $80=READ

Cflag			= $63		; comparison evaluation flag

TabSiz		= $64		; TAB step size (was input flag)

next_s		= $65		; next descriptor stack address

					; these two bytes form a word pointer to the item
					; currently on top of the descriptor stack
last_sl		= $66		; last descriptor stack address low byte
last_sh		= $67		; last descriptor stack address high byte (always $00)

des_sk		= $68		; descriptor stack start address (temp strings)

;			= $70		; End of descriptor stack

ut1_pl		= $71		; utility pointer 1 low byte
ut1_ph		= ut1_pl+1	; utility pointer 1 high byte
ut2_pl		= $73		; utility pointer 2 low byte
ut2_ph		= ut2_pl+1	; utility pointer 2 high byte

Temp_2		= ut1_pl	; temp byte for block move	

FACt_1		= $75		; FAC temp mantissa1
FACt_2		= FACt_1+1	; FAC temp mantissa2
FACt_3		= FACt_2+1	; FAC temp mantissa3

dims_l		= FACt_2	; array dimension size low byte
dims_h		= FACt_3	; array dimension size high byte

TempB			= $78		; temp page 0 byte

Smeml			= $79		; start of mem low byte		(Start-of-Basic)
Smemh			= Smeml+1	; start of mem high byte	(Start-of-Basic)
Svarl			= $7B		; start of vars low byte	(Start-of-Variables)
Svarh			= Svarl+1	; start of vars high byte	(Start-of-Variables)
Sarryl		= $7D		; var mem end low byte		(Start-of-Arrays)
Sarryh		= Sarryl+1	; var mem end high byte		(Start-of-Arrays)
Earryl		= $7F		; array mem end low byte	(End-of-Arrays)
Earryh		= Earryl+1	; array mem end high byte	(End-of-Arrays)
Sstorl		= $81		; string storage low byte	(String storage (moving down))
Sstorh		= Sstorl+1	; string storage high byte	(String storage (moving down))
Sutill		= $83		; string utility ptr low byte
Sutilh		= Sutill+1	; string utility ptr high byte
Ememl			= $85		; end of mem low byte		(Limit-of-memory)
Ememh			= Ememl+1	; end of mem high byte		(Limit-of-memory)
Clinel		= $87		; current line low byte		(Basic line number)
Clineh		= Clinel+1	; current line high byte	(Basic line number)
Blinel		= $89		; break line low byte		(Previous Basic line number)
Blineh		= Blinel+1	; break line high byte		(Previous Basic line number)

Cpntrl		= $8B		; continue pointer low byte
Cpntrh		= Cpntrl+1	; continue pointer high byte

Dlinel		= $8D		; current DATA line low byte
Dlineh		= Dlinel+1	; current DATA line high byte

Dptrl			= $8F		; DATA pointer low byte
Dptrh			= Dptrl+1	; DATA pointer high byte

Rdptrl		= $91		; read pointer low byte
Rdptrh		= Rdptrl+1	; read pointer high byte

Varnm1		= $93		; current var name 1st byte
Varnm2		= Varnm1+1	; current var name 2nd byte

Cvaral		= $95		; current var address low byte
Cvarah		= Cvaral+1	; current var address high byte

Frnxtl		= $97		; var pointer for FOR/NEXT low byte
Frnxth		= Frnxtl+1	; var pointer for FOR/NEXT high byte

Tidx1			= Frnxtl	; temp line index

Lvarpl		= Frnxtl	; let var pointer low byte
Lvarph		= Frnxth	; let var pointer high byte

prstk			= $99		; precedence stacked flag

comp_f		= $9B		; compare function flag, bits 0,1 and 2 used
					; bit 2 set if >
					; bit 1 set if =
					; bit 0 set if <

func_l		= $9C		; function pointer low byte
func_h		= func_l+1	; function pointer high byte

garb_l		= func_l	; garbage collection working pointer low byte
garb_h		= func_h	; garbage collection working pointer high byte

des_2l		= $9E		; string descriptor_2 pointer low byte
des_2h		= des_2l+1	; string descriptor_2 pointer high byte

g_step		= $A0		; garbage collect step size

Fnxjmp		= $A1		; jump vector for functions
Fnxjpl		= Fnxjmp+1	; functions jump vector low byte
Fnxjph		= Fnxjmp+2	; functions jump vector high byte

g_indx		= Fnxjpl	; garbage collect temp index

FAC2_r		= $A3		; FAC2 rounding byte

Adatal		= $A4		; array data pointer low byte
Adatah		= Adatal+1	; array data pointer high  byte

Nbendl		= Adatal	; new block end pointer low byte
Nbendh		= Adatah	; new block end pointer high  byte

Obendl		= $A6		; old block end pointer low byte
Obendh		= Obendl+1	; old block end pointer high  byte

numexp		= $A8		; string to float number exponent count
expcnt		= $A9		; string to float exponent count

numbit		= numexp	; bit count for array element calculations

numdpf		= $AA		; string to float decimal point flag
expneg		= $AB		; string to float eval exponent -ve flag

Astrtl		= numdpf	; array start pointer low byte
Astrth		= expneg	; array start pointer high  byte

Histrl		= numdpf	; highest string low byte
Histrh		= expneg	; highest string high  byte

Baslnl		= numdpf	; BASIC search line pointer low byte
Baslnh		= expneg	; BASIC search line pointer high  byte

Fvar_l		= numdpf	; find/found variable pointer low byte
Fvar_h		= expneg	; find/found variable pointer high  byte

Ostrtl		= numdpf	; old block start pointer low byte
Ostrth		= expneg	; old block start pointer high  byte
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

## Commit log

2023-12-22 time at which file control was changed from renaming files to actually using git revisions prior to this are under /BAK
    [65C02_Pocket_3v3.sch, 65C02_Pocket_IDE_CF_3v3.sch, ASM304.obj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]
2023-12-22 converting to git
    [16c550.kicad_sch, 6502.kicad_sch, 65c21.kicad_sch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]
2023-12-23 Restructuring, adding hardware to repository
    make_opti.bat directories adjusted for changes
    [65C02_Pocket_3v3.sch, 65C02_Pocket_IDE_CF_3v3.sch, ASM304.obj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]
2024-01-09 Added to Bios B_RX_Char B_TX_Char B_COMM_Set_Speed All BankSwitch routines B_Nybble_Swap B_VER
    also Added Some of the i2c routines
    I2C_Init (for routine)
    I2C_Main
    I2C_Write
    I2C_Ack_Read
    added project for Si5351a
2024-01-10 Adjusted I2C_Ack_Nack_Write to use I2C_Write routine
2024-01-10 weird. idk why it made me change it
    [clk.kicad_sch, power.kicad_sch]
2024-01-10 Added I2C_Read and converted I2C_Read_Ack to use I2C_Read routine
2024-01-10 Added B_TIME_Count and irq handling of timer
    timing.txt: info on timer counting abilities
    Added wdc programming manual: Programmingthe65816_ProgManual 1986.pdf
    added additional register file for when out2 is at 2 MHz: VCM-Registersout2.h
2024-01-11 Hardware: fixed error in schematic with clock moved dotclock to out 2 (better for jitter) allowed the replacement of 82c54 CPU CLK with CLK 2 moved nmi switch to a more reasonable location
    [65c21.kicad_sch, 82c54.kicad_sch, IO.kicad_sch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]
2024-01-11 Hardware: fixed error in schematic with clock moved dotclock to out 2 (better for jitter) allowed the replacement of 82c54 CPU CLK with CLK 2 moved nmi switch to a more reasonable location
    software:
    added timing info to count subroutine
    Reference:
    Added documentation on si5351 registers
    [Bios.asm]
2024-01-13 added comments to i2c routine
2024-01-13 B_TIME_Delay: replaced ROL SEC ROR with TSB (save 5 cycles 2bytes)
    B_COMM_Set_Speed: replace ADC STA with TSB (2 cycles, 3 bytes)
    Replace LDA SEC SBC STA 12 with LDA TRB (4 cycles, 5 bytes)
    [Bios.asm]
2024-01-13 Fixed error in TIE LE signal (Logic was inverted, replaced or with nor)
    [IO.kicad_sch, IO_GLUE.kicad_sch]
2024-01-22 Finallized board, added jumpers for debug, added reset to Ext connector other errors fixed
    [6502.kicad_sch, IO_GLUE.kicad_sch, Micro.kicad_sch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]
2024-01-22 Bios: B_COMM_TX_Char changed to wait until Char is sent in order to exit B_COMM_MoveCsr vt100 move cursor command added B_ReadKey Added command to read key to buffer @$0200 Fixed error in B_TIME_Dela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
    Added missing STA to IRQ-Timer
    Started on IRQ_COMM
    added IRQ_Key Routine
    [Bios.asm, IO_DEF.asm]
2024-02-05 Bios: ZP mapping changed fixing incorrect syntax and typos Added bios jump table for bios calls (in Bios.inc) slightly renamed some functions Added I2C_Stop Added 16 bit multi+Div made sure unoccupie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
    ROM.asm: created makefile basically
    Moved documentation to /Documentation
    [vmc.cfg]
2024-02-13 Trimmed Files (.bak .o .bin)
    PLL/VCM-Design-Report.txt : updated to correct specification (as of 2/13/24)
    vmc_fe.cfg : updated to correct rom size and corrected offset
    Rudimentery/rudimentery_optimized.asm : fixed indirect jump from incorrect mem address
    [vmc_fe.cfg]
2024-02-16 Prep for merge into main repo
    [16c550.kicad_sch, 6502.kicad_sch, 65c21.kicad_sch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]
2024-02-26 RLE/RLE.asm: added mode 1, fixed errors Bios.asm: moved ZP defs to ZP.inc, added .include for RLE.asm Bios.inc: added .segment, updated B_DATA_RLE_Decode ROM.asm: Adjusted for linker vmc.cfg: adjuste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
    Sound/n163_inf.txt: info on namco 163, used for research into sound hardware
    [vmc.cfg]
2024-03-21 RLE.asm: added start to mode 4 Micro_Probe_Pinout.xlsx : added pinout Reference/Misc/: added mascot and associated versions Tools/RLE Encode/src/: c program to encode raw binary to mode_1 rle
    [Micro_Probe_Pinout.xlsx, test.csv]
